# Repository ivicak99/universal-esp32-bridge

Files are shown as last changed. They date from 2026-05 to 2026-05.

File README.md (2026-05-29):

# Universal ESP32 Button/Signal Bridge

Compact **ESP32-S3** board for personal automation — safely interfaces with low-voltage
buttons, LEDs, buzzers, and control panels (intercoms, appliance panels, remotes,
ventilation controls).

> ⚠️ **LOW VOLTAGE ONLY — NOT designed to switch 230 V mains.** Relays use low-voltage
> contacts only.

**Status:** paper design, rev 0.1 (schematic notes + KiCad project skeleton; not yet
laid out or prototyped).

## Features

- **ESP32-S3-WROOM-1-N8** module (pre-certified, no PSRAM so GPIO35/36/37 stay free)
- USB-C power + **native USB-Serial-JTAG** programming (no CH340/CP2102 needed)
- 5 V external input + AMS1117-3.3 regulator
- **8** optically isolated inputs (≈3–24 V DC, constant-current front end, active-low)
- **8** PhotoMOS isolated dry-contact outputs (AQY212GS, ≤60 V / ≤0.5 A)
- **2** optional mechanical relay outputs (MOSFET-driven, flyback, LV contacts only)
- **4** capacitive-touch injection outputs (100 k / 470 k / 1 M selectable)
- Status LED, BOOT + RESET buttons, UART debug + spare-GPIO headers
- Screw terminals + test points; 4-layer; 0603-min passives; JLCPCB/LCSC sourcing

## Files

| File | Description |
|---|---|
| [DESIGN.md](DESIGN.md) | Block diagram, GPIO map, strapping-pin policy, per-block schematics, ERC/DRC notes, warnings, I/O-expander fallback |
| [BOM.csv](BOM.csv) | Bill of materials with example parts / LCSC codes (verify before ordering) |
| [block-diagram.txt](block-diagram.txt) | ASCII block diagram |
| `universal-esp32-bridge.kicad_pro` | KiCad 8 project |
| `universal-esp32-bridge.kicad_sch` | Starter schematic (design notes embedded) |

## GPIO summary

23 signals on direct ESP32-S3 GPIO (inputs 4/5/6/7/15/16/17/18, PhotoMOS
8/9/10/11/12/13/14/21, relays 35/36, cap-inject 37/38/39/40, LED 2). Strapping pins
GPIO3/45/46 left unconnected; GPIO0 used only by BOOT button. See [DESIGN.md](DESIGN.md).

## Disclaimer

Unverified paper design. Build and bring up one channel of each type before populating
all channels. Confirm all part numbers and footprints before ordering.

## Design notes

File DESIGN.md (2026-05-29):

# Universal ESP32 Button/Signal Bridge — Design Package

**Rev:** 0.3 (ERC-clean, real footprints, tidied for review)
**Date:** 2026-05-29
**MCU module:** ESP32-S3-WROOM-1-N8 (8 MB flash, **no** PSRAM — chosen so GPIO35/36/37 stay free)
**Regulator:** SY8089AAAC buck (2.7–5.5 V in, 2 A) → 3.3 V  *(replaced AMS1117 for Wi-Fi-peak headroom)*
**PCB:** 4-layer, signal / GND / PWR / signal
**Passives:** 0603 minimum (0805/1206 where power dictates). No 0201/01005.
**Sourcing target:** JLCPCB / LCSC

> ⚠️ **SAFETY / SCOPE**
> This board is for **low-voltage signal-level** automation only (≈3–24 V DC on inputs,
> ≤60 V / ≤0.5 A on isolated outputs). It is **NOT designed to switch 230 V mains** and
> must never be wired to mains. The mechanical relays use low-voltage contacts only.
> Silk legend to print: **"LOW VOLTAGE ONLY — NOT FOR MAINS (230 V) SWITCHING".**

---

## 0. Realized KiCad schematic (rev 0.3) — STATUS

The paper design is now a **real, ERC-clean KiCad 10 hierarchical schematic** with actual
library symbols, **datasheet-accurate footprints**, and a **tidied, human-readable layout**
(each pin routed to an offset net label; channels laid out as clean columns). **No PCB
layout yet** (per instruction — layout waits until you're happy with the schematic).

**Rev 0.3 changes:**
- **HK4100F-DC5V-SHG footprint built** (6-pad THT land pattern from the LCSC/EasyEDA part,
  matches datasheet 15.5×10.5 mm). Pin map: coil = 3/4, COM = 5/6 (tied), NO = 1, NC = 2.
  Custom symbol added so symbol pins match footprint pads. *(NO/NC could be swapped —
  low-risk, confirm against datasheet at build.)*
- **AQY212GS footprint corrected** to SOP-4 **2.54 mm pitch** (LS 6.8 mm) — the earlier
  1.27 mm assumption was wrong. Pinout confirmed 1=A, 2=K, 3/4=load.
- **EL357N LCSC code corrected to C6649** (the previous C124981 was a trimmer pot, not the
  opto!). Package confirmed SOP-4 2.54 mm; footprint generated.
- Footprints `bridge:HK4100F-DC5V-SHG`, `bridge:AQY212GS_SOP-4`, `bridge:EL357N_SOP-4`
  live in `footprints/bridge.pretty/` (generated via easyeda2kicad from the LCSC parts).
- Schematic re-laid-out for readability (bigger pages for the 8-channel sheets; labels
  offset from pins on short stubs routed by each pin's true orientation).

**ERC result:** `0 errors, 0 warnings` (KiCad 10.0.3 `kicad-cli sch erc`). Netlist verified:
160 components, 121 nets; rails, FB divider, reset/boot, relay coils all correctly wired;
**galvanic isolation barrier confirmed intact** (no field-side input/output net touches GND
or the ESP32).

**Project files (repo root):**
| File | Contents |
|---|---|
| `universal-esp32-bridge.kicad_sch` | Root sheet (instantiates the 6 child sheets) |
| `power.kicad_sch` | USB-C, diode-OR, SY8089 buck, rails, test points |
| `mcu.kicad_sch` | ESP32-S3-WROOM-1, reset/boot, status LED, UART + spare headers |
| `inputs.kicad_sch` | 8× isolated input channels |
| `photomos.kicad_sch` | 8× PhotoMOS dry-contact outputs |
| `relays.kicad_sch` | 2× relay channels |
| `capinject.kicad_sch` | 4× cap-injection channels |
| `bridge.kicad_sym` | Custom symbols: SY8089, AQY212GS |
| `sym-lib-table` / `fp-lib-table` | Point to KiCad 10 global libs + the custom lib |
| `schematic.pdf` | Rendered schematic (view without KiCad) |
| `gen/` | Python generator (`build.py`, `kisch.py`) that emits the project |

**Two engineering changes made while realizing the design:**
1. **Regulator → SY8089 buck.** AMS1117's dropout was marginal on the ~4.6 V diode-OR rail
   at Wi-Fi peaks. SY8089 (2.7–5.5 V in) handles the low rail with margin and is more
   efficient. FB divider R3=453 k / R4=100 k → 3.32 V.
2. **Input front-end → fixed 2.2 kΩ (1206), not a CRD.** Constant-current diodes are poorly
   stocked on LCSC. A 2.2 kΩ/1206 series resistor + the high-CTR EL357N covers 3–24 V
   (≈0.9 mA→10 mA) and the 1206 handles the ~0.24 W at 24 V. Anti-parallel 1N4148WS gives
   reverse protection. (A CRD is still a valid swap if you prefer constant current.)

**To regenerate / re-run ERC:**
```
cd gen && python3 build.py
/Applications/KiCad/KiCad.app/Contents/MacOS/kicad-cli sch erc \
    ../universal-esp32-bridge.kicad_sch --exit-code-violations
```

---

## 1. Block Diagram

```
                              USB-C (power + native USB-Serial-JTAG)
                                 │ VBUS 5V        │ D+ / D-
                                 │                │ (GPIO20 / GPIO19)
                  ┌──────────────┴───┐        ┌───┴───────────────┐
   EXT 5V IN ───►│  Diode-OR (SS54)  │        │ USBLC6-2SC6 ESD    │
   (screw term)  │  reverse-prot     │        └───┬───────────────┘
                 └──────────┬────────┘            │
                            │ 5V rail (~4.6V)      │
              ┌─────────────┼──────────────┐      │
              │             │              │      │
        ┌─────┴─────┐  ┌────┴─────┐   ┌────┴──────┴──────────────────┐
        │ AMS1117-  │  │ Relay    │   │      ESP32-S3-WROOM-1-N8       │
        │ 3.3 LDO   │  │ coils 5V │   │  (3.3V, native USB, buttons)  │
        └─────┬─────┘  └────┬─────┘   └──┬───┬────┬────┬────┬────┬─────┘
              │ 3.3V rail   │            │   │    │    │    │    │
              ├─────────────┼────────────┘   │    │    │    │    │
              │             │                 │    │    │    │    │
   ┌──────────┴───┐  ┌──────┴──────┐  ┌──────┴─┐ ┌┴────┴┐ ┌─┴────┴─┐
   │ 8× ISOLATED  │  │ 8× PhotoMOS │  │ 2× RLY │ │4× CAP│ │ STATUS │
   │ INPUTS       │  │ DRY-CONTACT │  │ driver │ │ inject│ │ LED    │
   │ (opto + CRD) │  │ OUTPUTS     │  │ +flybk │ │ 100k/ │ │ GPIO2  │
   │ 3–24V DC     │  │ ≤60V/≤0.5A  │  │ MOSFET │ │ 470k/ │ └────────┘
   └──────┬───────┘  └──────┬──────┘  └───┬────┘ │ 1M    │
          │                 │             │      └──┬────┘
     screw terminals   screw terminals  screw t.  pads/term
     IN1..IN8 (+/-)    OUT1..OUT8 (A/B) RLY1/2    CAP1..4

   Test points: 3V3, 5V, GND, IN1..8 (logic side), OUT1..8, plus BOOT/EN.
```

Full-resolution block diagram source: see `block-diagram.txt`.

---

## 2. GPIO Pin Map (ESP32-S3-WROOM-1)

**Reserved / avoided:** GPIO0 (BOOT strap), GPIO3 / GPIO45 / GPIO46 (straps),
GPIO19/GPIO20 (native USB D-/D+), GPIO43/GPIO44 (UART0 console — kept free for debug).

| Function | Signal | GPIO | Notes |
|---|---|---|---|
| Isolated input 1  | IN1 | GPIO4  | opto pulls LOW when external signal present |
| Isolated input 2  | IN2 | GPIO5  | (active-low, invert in firmware) |
| Isolated input 3  | IN3 | GPIO6  | |
| Isolated input 4  | IN4 | GPIO7  | |
| Isolated input 5  | IN5 | GPIO15 | |
| Isolated input 6  | IN6 | GPIO16 | |
| Isolated input 7  | IN7 | GPIO17 | |
| Isolated input 8  | IN8 | GPIO18 | |
| PhotoMOS out 1 | OUT1 | GPIO8  | HIGH = contact closed |
| PhotoMOS out 2 | OUT2 | GPIO9  | |
| PhotoMOS out 3 | OUT3 | GPIO10 | |
| PhotoMOS out 4 | OUT4 | GPIO11 | |
| PhotoMOS out 5 | OUT5 | GPIO12 | |
| PhotoMOS out 6 | OUT6 | GPIO13 | |
| PhotoMOS out 7 | OUT7 | GPIO14 | |
| PhotoMOS out 8 | OUT8 | GPIO21 | |
| Relay 1 drive | RLY1 | GPIO35 | via MOSFET; HIGH = energized |
| Relay 2 drive | RLY2 | GPIO36 | |
| Cap inject 1 | CAP1 | GPIO37 | through 100k/470k/1M jumper |
| Cap inject 2 | CAP2 | GPIO38 | |
| Cap inject 3 | CAP3 | GPIO39 | |
| Cap inject 4 | CAP4 | GPIO40 | |
| Status LED | LED | GPIO2  | active-high through 1k |
| Boot button | — | GPIO0  | strap, 10k PU + 0.1µF, button to GND |
| Reset button | — | EN | 10k PU + 1µF, button to GND |
| USB D- | — | GPIO19 | native USB-Serial-JTAG |
| USB D+ | — | GPIO20 | |
| (free / spare) | — | GPIO1, GPIO41, GPIO42, GPIO47, GPIO48 | bring to a header for future use |

**23 signals assigned, 5 GPIOs spare.** GPIO35/36/37 are only free on **non-PSRAM**
modules (N8). If you buy an `R8` (octal PSRAM) variant, those three pins disappear —
re-map relays/cap1 to spares (GPIO47/48/41).

### 2.1 Strapping-pin handling (explicit)

ESP32-S3 has 4 strapping pins sampled at reset. This design's policy:

| Strap pin | Default latch | Used in this design? | Handling |
|---|---|---|---|
| GPIO0 | 1 = SPI boot  | **Yes — BOOT button** | 10k pull-up + 0.1µF + button to GND. Default HIGH = normal boot; pull LOW only while pressing BOOT. No other load on this net. |
| GPIO3 | float = JTAG src | **No** | Left unconnected (no-connect flag). Not routed to any channel. |
| GPIO45 | 0 = VDD_SPI 3.3V | **No** | Left unconnected. Do not load — must read its default at boot. |
| GPIO46 | 0 (ROM msg ctrl), input-only | **No** | Left unconnected. Input-only anyway, so never used as an output. |

No isolated-input, PhotoMOS, relay, or cap-inject channel is mapped onto a strapping
pin. The only strap intentionally driven is GPIO0, and only by the BOOT button — exactly
its intended ESP-IDF use. This keeps power-on boot deterministic.

> Also note GPIO19/20 (USB) and GPIO43/44 (UART0) are reserved, not channel pins.

### 2.2 I/O Expander Option (fallback — NOT used in V1)

**V1 default = direct ESP32-S3 GPIO** for every channel (28 usable pins ≥ 23 needed, so
no expander is required and none is fitted). This section documents the fallback **only**
for the case where layout/routing of 22 channel traces to the module proves too messy on
the chosen board size — per your instruction, propose the expander before ever cutting
channels.

**Proposed expander: MCP23017** (16-bit I²C GPIO expander, 0603-friendly SSOP/SOIC,
on LCSC, 5V/3.3V tolerant, two address pins → up to 8 on one bus, has INT outputs).

What moves to the expander vs. stays direct:

| Channel group | On expander? | Why |
|---|---|-----|
| 8 PhotoMOS outputs | ✅ yes | Slow on/off; I²C latency irrelevant. |
| 2 relay outputs | ✅ yes | Same — set-and-forget. |
| Status LED | ✅ yes | Trivial. |
| 8 isolated inputs | ⚠️ optional | OK via MCP23017 INT pin → 1 ESP32 GPIO interrupt; on-chip pull-ups + INT-on-change. Slightly more firmware. |
| **4 cap-inject** | ❌ **stay direct** | Charge-transfer timing needs real-time GPIO toggling — an I²C expander is far too slow. Always on native ESP32 GPIO. |

**Two sizing options:**
- **1× MCP23017** → all 8 PhotoMOS + 2 relays + status LED (11 of 16 pins). Inputs + 4
  cap-inject stay on direct GPIO. Frees ~11 ESP32 pins. Cost: 1 chip, I²C (SDA/SCL =
  e.g. GPIO8/GPIO9) + 1 INT line if you later move inputs over.
- **2× MCP23017** (addresses 0x20/0x21) → bank A = 8 outputs+2 relays+LED, bank B = 8
  inputs (with INT). Only cap-inject + I²C + INTs remain direct: **~6 ESP32 GPIOs total.**
  This is also what would let a pin-limited C3 run the full board — but we are staying on
  S3, so this is purely a routing-relief option.

**Trade-offs to weigh before choosing it:**
- Adds I²C bus (2 pull-ups 4.7k), 1–2 chips, decoupling — more BOM, but *fewer* long
  channel traces fanning out to the module (often a net routing win on a dense 4-layer).
- Output update rate via I²C is ~fine (sub-ms for a few pins); inputs lose hardware
  per-pin interrupt granularity (one shared INT, read register to find which pin).
- Firmware: ESPHome has an `mcp23017`/`mcp23xxx` platform, so channels still expose
  cleanly later.

**Decision for V1: do NOT populate an expander.** Keep the MCP23017 footprint(s) + I²C
pull-ups as an **optional DNP footprint** on the board if you want a no-respin escape
hatch; otherwise route direct. Revisit only if 4-layer routing of the 22 channels can't
close at the target board size.

---

## 3. Schematic Design (per-block, as readable netlists)

Reference designators below match the KiCad skeleton sheets you'll wire up.

### 3.1 Power

```
USB-C J1:
  VBUS ──► D1 (SS54 Schottky, anode VBUS, cathode 5V_RAIL)
  CC1 ── R1 5.1k ── GND        (Rd, sink advertise)
  CC2 ── R2 5.1k ── GND
  D+/D- ── USBLC6-2SC6 (U2) ── GPIO20 / GPIO19   (ESD clamp + pass-through)
  SHIELD ── (NP) ── chassis/GND via 1M ∥ 4.7nF footprint

EXT 5V screw terminal J2 (5V, GND):
  5V_in ──► D2 (SS54, anode in, cathode 5V_RAIL)   (reverse-protect + OR with USB)

5V_RAIL:
  C1 100µF (1206/electrolytic) + C2 0.1µF  to GND   (bulk)
  ──► AMS1117-3.3 (U3) IN
       U3 OUT = 3V3_RAIL
       C3 22µF + C4 0.1µF on OUT to GND

3V3_RAIL:
  C5 22µF + C6 10µF + C7 0.1µF near module 3V3 pin
  TVS optional footprint D3 (SMAJ5.0A) across 5V_RAIL→GND
```

> Note: diode-OR drops the rail to ≈4.6 V. AMS1117 dropout at ~500 mA is ~1 V, leaving
> ~3.5 V headroom for the 3.3 V output — adequate but not generous. See Warnings §7.

### 3.2 ESP32-S3 module (U4 = ESP32-S3-WROOM-1-N8)

```
3V3 ── module 3V3, decoupled as above
EN  ── R3 10k to 3V3 ; C8 1µF to GND ; SW1 (RESET) to GND
GPIO0 ── R4 10k to 3V3 ; C9 0.1µF to GND ; SW2 (BOOT) to GND
GPIO19 ── USB D- (via U2)
GPIO20 ── USB D+ (via U2)
GPIO43/44 (U0TXD/RXD) ── 3-pin debug header J3 (TX, RX, GND)
Spare GPIOs (1,41,42,47,48) ── 5-pin expansion header J4
GND ── module GND pads + thermal pad
```

### 3.3 Isolated Input channel (×8, IN1…IN8) — repeat block

```
Screw terminal Jx (IN+, IN-):
  IN+ ──► CRD1 (constant-current diode ~2 mA, e.g. 1N5305 / CRD-2mA)
        ──► opto LED anode (U_INx, EL357N)
  opto LED cathode ──► IN-
  D_revx (1N4148WS) anti-parallel across opto LED (reverse clamp)
  TVS optional footprint (SMAJ24A) across IN+/IN-   [DNP default]

Opto output side (EL357N transistor):
  collector ──► R_pux 10k to 3V3   AND  ──► node INx_LOGIC
  emitter   ──► GND
  Optional RC filter footprint:
      INx_LOGIC ── R_fx (1k, DNP/0Ω default) ── INx_FILT ── C_fx (100nF, DNP) ── GND
  INx_FILT (or INx_LOGIC if RC unpopulated) ──► ESP32 GPIO
  Test point TP_INx on the logic node.
```

- **Idle (no external signal):** opto off → GPIO pulled HIGH by 10k.
- **Signal present:** opto on → GPIO pulled LOW. Treat as **active-low** in firmware.
- CRD gives ~constant LED current from ~3 V to 24 V, so brightness/threshold is
  consistent across the whole range and the series resistor never overheats.
- CRD inherently blocks reverse polarity (it's a diode) → polarity protection built in.

### 3.4 PhotoMOS dry-contact output (×8, OUT1…OUT8) — repeat block

```
ESP32 GPIO ──► R_dx 330Ω ──► PhotoMOS LED anode (U_OUTx, AQY212GS)
                              PhotoMOS LED cathode ──► GND
PhotoMOS load pins (pins 4 & 6) ──► screw terminal Jx (OUTx_A, OUTx_B)
  Optional series footprint F_x (0Ω / fuse / PTC) in OUTx_A leg  [0Ω default]
  Optional TVS/snubber footprint across OUTx_A/B  [DNP]
Test point TP_OUTx on OUTx_A.
```

- ~6.4 mA LED drive from 3.3 V through 330 Ω (AQY212 trigger IF ≈ 3 mA → solid margin).
- Output is a **bidirectional isolated solid-state contact** (no polarity), behaves like
  a momentary/maintained button. AQY212GS: 60 V / 550 mA / ~0.5 Ω on-resistance.
- GPIO HIGH = contact closed.

### 3.5 Mechanical relay output (×2, RLY1/RLY2) — optional, repeat block

```
ESP32 GPIO ──► R_gx 100Ω ──► gate of Q_x (AO3400A, logic-level N-MOSFET)
  R_pdx 100k gate-to-GND (hold off during boot)
  Q_x source ──► GND
  Q_x drain  ──► relay coil (-)   [K_x = HK4100F-DC5V or G5NB-1A-E-5VDC]
  relay coil (+) ──► 5V_RAIL
  D_fbx flyback (1N4007/M7 or SS14) across coil, cathode to 5V
Relay contacts (COM / NO [/ NC]) ──► screw terminal Jx
  Optional RC snubber footprint across contacts  [DNP]
Silk: "LV CONTACTS ONLY"
```

- Driven by MOSFET, never directly from the GPIO. Gate pulldown keeps relay off while
  GPIO0/straps settle at boot. Flyback diode mandatory.

### 3.6 Capacitive injection output (×4, CAP1…CAP4) — repeat block

```
ESP32 GPIO ──► three parallel 0603 resistor footprints to common node CAPx_OUT:
      R_100k  (100 kΩ)   } populate ONE, or use solder-jumper SJ_x to select
      R_470k  (470 kΩ)   }
      R_1M    (1 MΩ)     }
CAPx_OUT ──► 2-pin terminal / pad to external touch pad
  Optional series C footprint (DNP) + ESD diode footprint (DNP)
Test point TP_CAPx.
```

- Default-populate 470 kΩ; leave the other two unpopulated. Or fit all three and select
  with the solder jumper. High series R limits current and lets the GPIO inject a
  charge-transfer signal into an external capacitive pad for experimentation.

### 3.7 Status LED

```
GPIO2 ──► R_led 1k ──► LED1 (0603, green) ──► GND   (active-high)
```

---

## 4. Connectors & Test Points

| Ref | Type | Purpose |
|---|---|---|
| J1 | USB-C 16-pin SMD (TYPE-C-31-M-12) | Power + native USB programming |
| J2 | 2-pos 3.5 mm screw terminal | External 5 V in |
| IN1–IN8  | 2-pos 3.5 mm screw terminal (×8) | Isolated inputs (IN+/IN-) |
| OUT1–OUT8| 2-pos 3.5 mm screw terminal (×8) | PhotoMOS dry contacts (A/B) |
| RLY1–RLY2| 3-pos 3.5 mm screw terminal (×2) | Relay COM/NO/NC |
| CAP1–CAP4| 2-pos 3.5 mm screw terminal (×4) | Cap-inject outputs |
| J3 | 3-pin 2.54 header | UART0 debug (TX/RX/GND) |
| J4 | 5-pin 2.54 header | Spare GPIO expansion |
| TP_* | 1.0 mm test pads | 3V3, 5V, GND, IN1-8, OUT1-8 |

> JST-XH alternative: every 3.5 mm terminal footprint can be swapped for JST-XH if you
> prefer cable connectors — keep the same pin order. Pick one in layout; don't fit both.

---

## 5. Suggested BOM (real parts)

See `BOM.csv` for the machine-readable version. Highlights:

| Block | Part | Mfr / Example | LCSC* | Notes |
|---|---|---|---|---|
| MCU module | ESP32-S3-WROOM-1-N8 | Espressif | verify| pre-certified, no PSRAM |
| LDO 3.3V | AMS1117-3.3 | various | C6186 | 1 A, beginner-proof |
| USB-C conn | TYPE-C-31-M-12 (16P) | various | C165948 | power+USB |
| USB ESD | USBLC6-2SC6 | ST | C7519 | D+/D- clamp |
| OR/rev diode | SS54 (SMC) | various | C22452| low-Vf 5 A Schottky |
| Input opto | EL357N(B) (×8) | Everlight | C124981 | SMD, high CTR |
| Input CCR | constant-current diode ~2 mA (×8) | e.g. 1N5305 / CRD | verify| see Warnings §7 |
| Input clamp  | 1N4148WS (×8) | various | C2128 | reverse clamp |
| PhotoMOS | AQY212GS (×8) | Panasonic | verify| 60V/550mA/0.5Ω |
| PhotoMOS alt | CPC1017N (×8) | IXYS/Clare | verify| 60V/100mA cheap alt |
| Relay | HK4100F-DC5V (×2) | HuiKe | C39562| LV contacts only |
| Relay MOSFET | AO3400A (×2) | AOS | C20917| logic-level N-ch |
| Flyback | 1N4007 / M7 (×2) | various | C95872| across coil |
| Status LED | 0603 green | various | — | |
| Buttons | 6×3.5 mm SMD tact (×2) | various | C318884| BOOT + RESET |
| Bulk caps | 100µF/16V, 22µF, 10µF | various | — | power filtering |
| Passives | 0603 R/C as listed | various | — | 1% resistors |
| Terminals | 3.5 mm screw, 2P/3P | various | — | I/O |

\* **LCSC codes must be verified before ordering** — codes drift and packaging
varies. Treat the manufacturer part numbers as authoritative and confirm the LCSC
stock code + footprint on lcsc.com at order time.

---

## 6. ERC / DRC Notes

**ERC (schematic):**
- Every opto/PhotoMOS LED needs its series element (CRD or 330 Ω) — ERC won't catch a
  missing current limit; check manually.
- Mark `5V_RAIL`, `3V3_RAIL`, `GND` as global power nets; add a `PWR_FLAG` on the LDO
  output, the 5V rail, and GND or ERC will report "input power pin not driven".
- Set unused module pins to "unconnected" (place no-connect flags) to silence ERC.
- Active-low inputs are intentional — don't let ERC/firmware assume active-high.
- BOOT (GPIO0) and EN have pull-ups + caps; verify no other driver fights them.

**DRC (layout, 4-layer):**
- **Isolation:** keep a clearance gap (≥1.5–2 mm, ideally a routed slot) between the
  field side (screw terminals / opto+PhotoMOS LED-output pins, relay contacts) and the
  logic side. The whole point of the optos/PhotoMOS is galvanic isolation — don't pour
  the logic GND plane under the field-side terminals. Use separate "field" copper.
- Inputs at 24 V are low energy, but still give input traces ≥0.3 mm and terminal-to-
  terminal spacing per your terminal pitch.
- Relay coil + PhotoMOS traces that may carry up to 0.5 A: ≥0.4 mm (16 mil) traces.
- USB D+/D-: route as a loose differential pair, short, away from switching nodes;
  put the USBLC6 right at the connector.
- Decoupling caps within a few mm of the module 3V3 pin; bulk cap near the LDO.
- Thermal: AMS1117 needs copper pour on its tab for >300 mA continuous.
- Place the module antenna at a board edge with **keep-out** (no copper/plane under the
  antenna) per Espressif's WROOM-1 layout guide.
- Add fab fiducials + the "NOT FOR MAINS" silk legend.

---

## 7. Warnings & Uncertain Items

1. **Wide-range input current limiting (most important).** A single fixed resistor that
   gives enough opto current at 3 V *and* doesn't cook itself / over-drive the opto at
   24 V is not really possible (8:1 range). The design uses a **constant-current diode
   (CRD ~2 mA)** which solves this elegantly and adds reverse protection — but:
   - CRD knee voltage + opto Vf (~1.2 V) means the very bottom of the 3 V spec is
     marginal. Validate with your exact CRD; if 3 V must be rock-solid, pick a low-knee
     CRD or a lower-Vf opto.
   - **Alternative if you can't source a CRD on LCSC:** fit a series resistor instead
     (footprint provided), e.g. 2.2 kΩ in **1206** (handles the ~0.24 W at 24 V), and
     accept that current varies 1–10 mA across the range. The EL357N's high CTR copes.
     I left both footprints so you can choose at build time.

2. **LCSC part numbers — now verified for the key actives** against JLCPCB (May 2026):
   ESP32-S3-WROOM-1-N8 **C2913198**, SY8089AAAC **C78988**, AQY212GS **C719745**,
   HK4100F-DC5V-SHG **C12072**, USB-C TYPE-C-31-M-12 **C165948**, AO3400A **C20917**.
   EL357N corrected to **C6649** (the old C124981 was a trimmer pot — fixed). Still confirm
   before ordering: USBLC6-2SC6 (C7519), SS54 (C22452), 1N4148WS (C2128), M7 (C95872). Passives are generic.

3. **Power rail headroom — resolved by the buck.** Diode-OR'd 5 V rail sits at ~4.6 V.
   The **SY8089 buck (2.7–5.5 V in)** handles this with large margin, unlike the original
   AMS1117 LDO (marginal dropout at Wi-Fi peaks). If you ever revert to an LDO, use a
   low-Vf P-FET ideal-diode for the OR-ing instead of the Schottky.

10. **Relay footprint — built (rev 0.3).** Real 6-pad HK4100F land pattern now in
    `bridge.pretty`. Remaining low-risk item: **NO/NC pad assignment** (pins 1 vs 2) is from
    decoding the EasyEDA symbol; the relay still works if swapped (just relabel the terminal),
    but confirm against the HUIKE datasheet before final.

11. **Custom symbols (SY8089, AQY212GS, HK4100F) pinouts.** SY8089 from Silergy datasheet
    (1=EN,2=GND,3=LX,4=IN,5=FB). AQY212GS 1=A,2=K,3/4=load (bidirectional). HK4100F coil=3/4,
    COM=5/6, NO=1, NC=2. All symbol pins match their generated footprints' pad numbers.

4. **USB current.** With plain 5.1 k CC pulldowns you only guarantee USB default current
   (~500 mA). ESP32 WiFi + both relays + several PhotoMOS can exceed that. **Power the
   relays/heavy loads from the EXT 5 V terminal** if using both relays hard, or add a
   USB-PD/BC1.2 negotiator. Documented, not auto-handled.

5. **Native USB vs UART.** I used the S3's built-in USB-Serial-JTAG (GPIO19/20) → no
   CH340/CP2102 needed. Auto-download usually works without touching buttons, but BOOT +
   RESET are included for the cases where it doesn't. If you'd rather have a classic
   USB-UART bridge with auto-reset (DTR/RTS), that's a different sub-circuit.

6. **Module variant matters.** Buy **N8 (no PSRAM)**. An `R8`/octal-PSRAM module steals
   GPIO35/36/37 — the relay + CAP1 pins. Re-map to spares if you must use R8.

7. **Isolation is only as good as the layout.** The optos/PhotoMOS provide galvanic
   isolation, but a sloppy 4-layer pour that runs the logic ground plane under the
   field-side terminals destroys it. Respect the isolation gap in §6.

8. **Test-point count is large.** 3V3+5V+GND + 8 inputs + 8 outputs = 19 pads minimum.
   They eat board area; consider a debug header block instead of individual loops if
   space is tight.

9. **This is a paper design, not validated silicon.** No SPICE sim or prototype yet.
   Build one channel of each type first (1 input, 1 PhotoMOS, 1 relay, 1 cap) on the
   first article and bring up firmware before populating all 22 channels.

---

## 8. Firmware GPIO hints (for later — ESPHome/MQTT/Matter)

- Inputs: `binary_sensor` with `inverted: true` (active-low), add `delayed_on/off` or
  the on-board RC for buzzer/blinking sources.
- PhotoMOS outputs: `switch` / `output` (active-high). For "button press" use a momentary
  `on_press` → turn on, delay 100–300 ms, turn off.
- Relays: `switch`, active-high; consider `restore_mode: ALWAYS_OFF`.
- Cap inject: `output` (or `esp32_touch` experiments) — start LOW.
- Status LED: `light`/`status_led` on GPIO2.
- Do **not** assign anything to GPIO0/3/45/46 in firmware.

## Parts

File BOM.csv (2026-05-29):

Item | Qty | References | Value | Footprint | Manufacturer Part | LCSC | JLCPCB | Notes
1 | 1 | U3 | ESP32-S3-WROOM-1-N8 | RF_Module:ESP32-S3-WROOM-1 | ESP32-S3-WROOM-1-N8 | C2913198 | Yes | Buy N8 (no PSRAM) so GPIO35/36/37 stay free
2 | 1 | U2 | SY8089AAAC | Package_TO_SOT_SMD:SOT-23-5 | SY8089AAAC | C78988 | Yes | Buck 2.7-5.5Vin/2A; Vout=0.6*(1+R3/R4)
3 | 1 | U1 | USBLC6-2SC6 | Package_TO_SOT_SMD:SOT-23-6 | USBLC6-2SC6 | C7519 | Yes | USB D+/D- ESD (verify code)
4 | 1 | J1 | USB-C | Connector_USB:USB_C_Receptacle_HRO_TYPE-C-31-M-12 | TYPE-C-31-M-12 | C165948 | Yes | 16-pin USB2.0 Type-C
5 | 8 | U4-U11 | EL357N | bridge:EL357N_SOP-4 | EL357N(B)(TA)-G | C6649 | Yes | Input optocoupler SOP-4 2.54mm (LCSC code corrected from C124981)
6 | 8 | U12-U19 | AQY212GS | bridge:AQY212GS_SOP-4 | AQY212GS | C719745 | Yes | PhotoMOS 60V/1A; SOP-4 2.54mm pitch (LS6.8)
7 | 2 | K1;K2 | HK4100F-DC5V | bridge:HK4100F-DC5V-SHG | HK4100F-DC5V-SHG | C12072 | Yes | 6-pad land pattern from datasheet; coil=3/4 COM=5/6 NO=1 NC=2
8 | 2 | Q1;Q2 | AO3400A | Package_TO_SOT_SMD:SOT-23 | AO3400A | C20917 | Yes | Logic-level N-MOSFET relay driver
9 | 2 | D1;D2 | SS54 | Diode_SMD:D_SMC | SS54 | C22452 | Yes | Diode-OR / reverse protect (verify code)
10 | 8 | D4-D11 | 1N4148WS | Diode_SMD:D_SOD-323 | 1N4148WS | C2128 | Yes | Input anti-parallel reverse clamp
11 | 2 | D12;D13 | M7 | Diode_SMD:D_SMA | M7 (1N4007 SMD) | C95872 | Yes | Relay coil flyback
12 | 1 | D3 | LED green | LED_SMD:LED_0603_1608Metric | (any 0603 green) | - | Yes | Status LED on IO2
13 | 1 | L1 | 2.2uH | Inductor_SMD:L_1210_3225Metric | (2.2uH >=1A) | - | Yes | Buck inductor; pick >=1A Isat
14 | 8 | R8;R11;R14;R17;R20;R23;R26;R29 | 2.2k | Resistor_SMD:R_1206_3216Metric | (2.2k 1206) | - | Yes | Input current-limit (1206 for power at 24V)
15 | 8 | R32-R39 | 330 | Resistor_SMD:R_0603_1608Metric | (330 0603) | - | Yes | PhotoMOS LED drive
16 | 10 | R5;R6;R9;R12;R15;R18;R21;R24;R27;R30 | 10k | Resistor_SMD:R_0603_1608Metric | (10k 0603) | - | Yes | Input pull-ups + EN/BOOT pull-ups
17 | 9 | R7;R10;R13;R16;R19;R22;R25;R28;R31 | 1k | Resistor_SMD:R_0603_1608Metric | (1k 0603) | - | Yes | Input RC filter series + status LED
18 | 7 | R4;R41;R43;R44;R47;R50;R53 | 100k | Resistor_SMD:R_0603_1608Metric | (100k 0603) | - | Yes | FB-bottom + MOSFET gate pulldown + cap-inject(100k)
19 | 4 | R45;R48;R51;R54 | 470k | Resistor_SMD:R_0603_1608Metric | (470k 0603) | - | Yes | Cap-inject (default populate)
20 | 4 | R46;R49;R52;R55 | 1M | Resistor_SMD:R_0603_1608Metric | (1M 0603) | - | Yes | Cap-inject option
21 | 1 | R3 | 453k | Resistor_SMD:R_0603_1608Metric | (453k 0603 1%) | - | Yes | Buck FB top -> 3.32V
22 | 2 | R40;R42 | 100 | Resistor_SMD:R_0603_1608Metric | (100 0603) | - | Yes | MOSFET gate series
23 | 2 | R1;R2 | 5.1k | Resistor_SMD:R_0603_1608Metric | (5.1k 0603) | - | Yes | USB-C CC Rd pulldowns
24 | 12 | C2;C6;C7;C8;C10-C17 | 100nF | Capacitor_SMD:C_0603_1608Metric | (100nF X7R 0603) | - | Yes | Decoupling + input RC + BOOT
25 | 2 | C3;C4 | 22uF | Capacitor_SMD:C_0805_2012Metric | (22uF 10V X7R 0805) | - | Yes | Buck in/out
26 | 1 | C1 | 100uF | Capacitor_SMD:C_1206_3216Metric | (100uF 16V) | - | Yes | 5V bulk
27 | 1 | C5 | 1uF | Capacitor_SMD:C_0603_1608Metric | (1uF 0603) | - | Yes | EN RC
28 | 1 | C9 | 10uF | Capacitor_SMD:C_0603_1608Metric | (10uF 0603) | - | Yes | 3V3 bulk near module
29 | 2 | SW1;SW2 | tactile | Button_Switch_SMD:Panasonic_EVQPUJ_EVQPUA | (SMD tact) | - | Yes | RESET + BOOT (verify exact button/footprint)
30 | 21 | J2;J5-J20;J23-J26 | Screw term 2P | TerminalBlock:TerminalBlock_MaiXu_MX126-5.0-02P_1x02_P5.00mm | (5.0mm 2P) | - | Yes | EXT5V + 8 inputs + 8 PhotoMOS + 4 cap-inject
31 | 2 | J21;J22 | Screw term 3P | TerminalBlock:TerminalBlock_MaiXu_MX126-5.0-03P_1x03_P5.00mm | (5.0mm 3P) | - | Yes | Relay COM/NO/NC
32 | 1 | J3 | Header 1x3 | Connector_PinHeader_2.54mm:PinHeader_1x03_P2.54mm_Vertical | (2.54 1x3) | - | Yes | UART debug
33 | 1 | J4 | Header 1x6 | Connector_PinHeader_2.54mm:PinHeader_1x06_P2.54mm_Vertical | (2.54 1x6) | - | Yes | Spare GPIO + GND
34 | 23 | TP1-TP23 | TestPoint | TestPoint:TestPoint_Pad_D1.5mm | (pad) | - | n/a | 3V3/5V/GND/IN1-8/OUT1-8/CAP1-4
NOTE |  |  |  |  |  |  |  | Cap-inject: schematic carries all 3 R per channel (100k/470k/1M); POPULATE ONE (default 470k). So actual populated cap-inject R = 4, not 12.
NOTE |  |  |  |  |  |  |  | LCSC codes verified against JLCPCB May 2026: ESP32 C2913198, buck C78988, EL357N C6649, AQY212GS C719745, relay C12072, USB-C C165948, AO3400A C20917.
NOTE |  |  |  |  |  |  |  | bridge:* footprints (relay/PhotoMOS/opto) generated from EasyEDA/LCSC (datasheet-accurate) and live in footprints/bridge.pretty. HK4100F NO/NC could be swapped - confirm before final.

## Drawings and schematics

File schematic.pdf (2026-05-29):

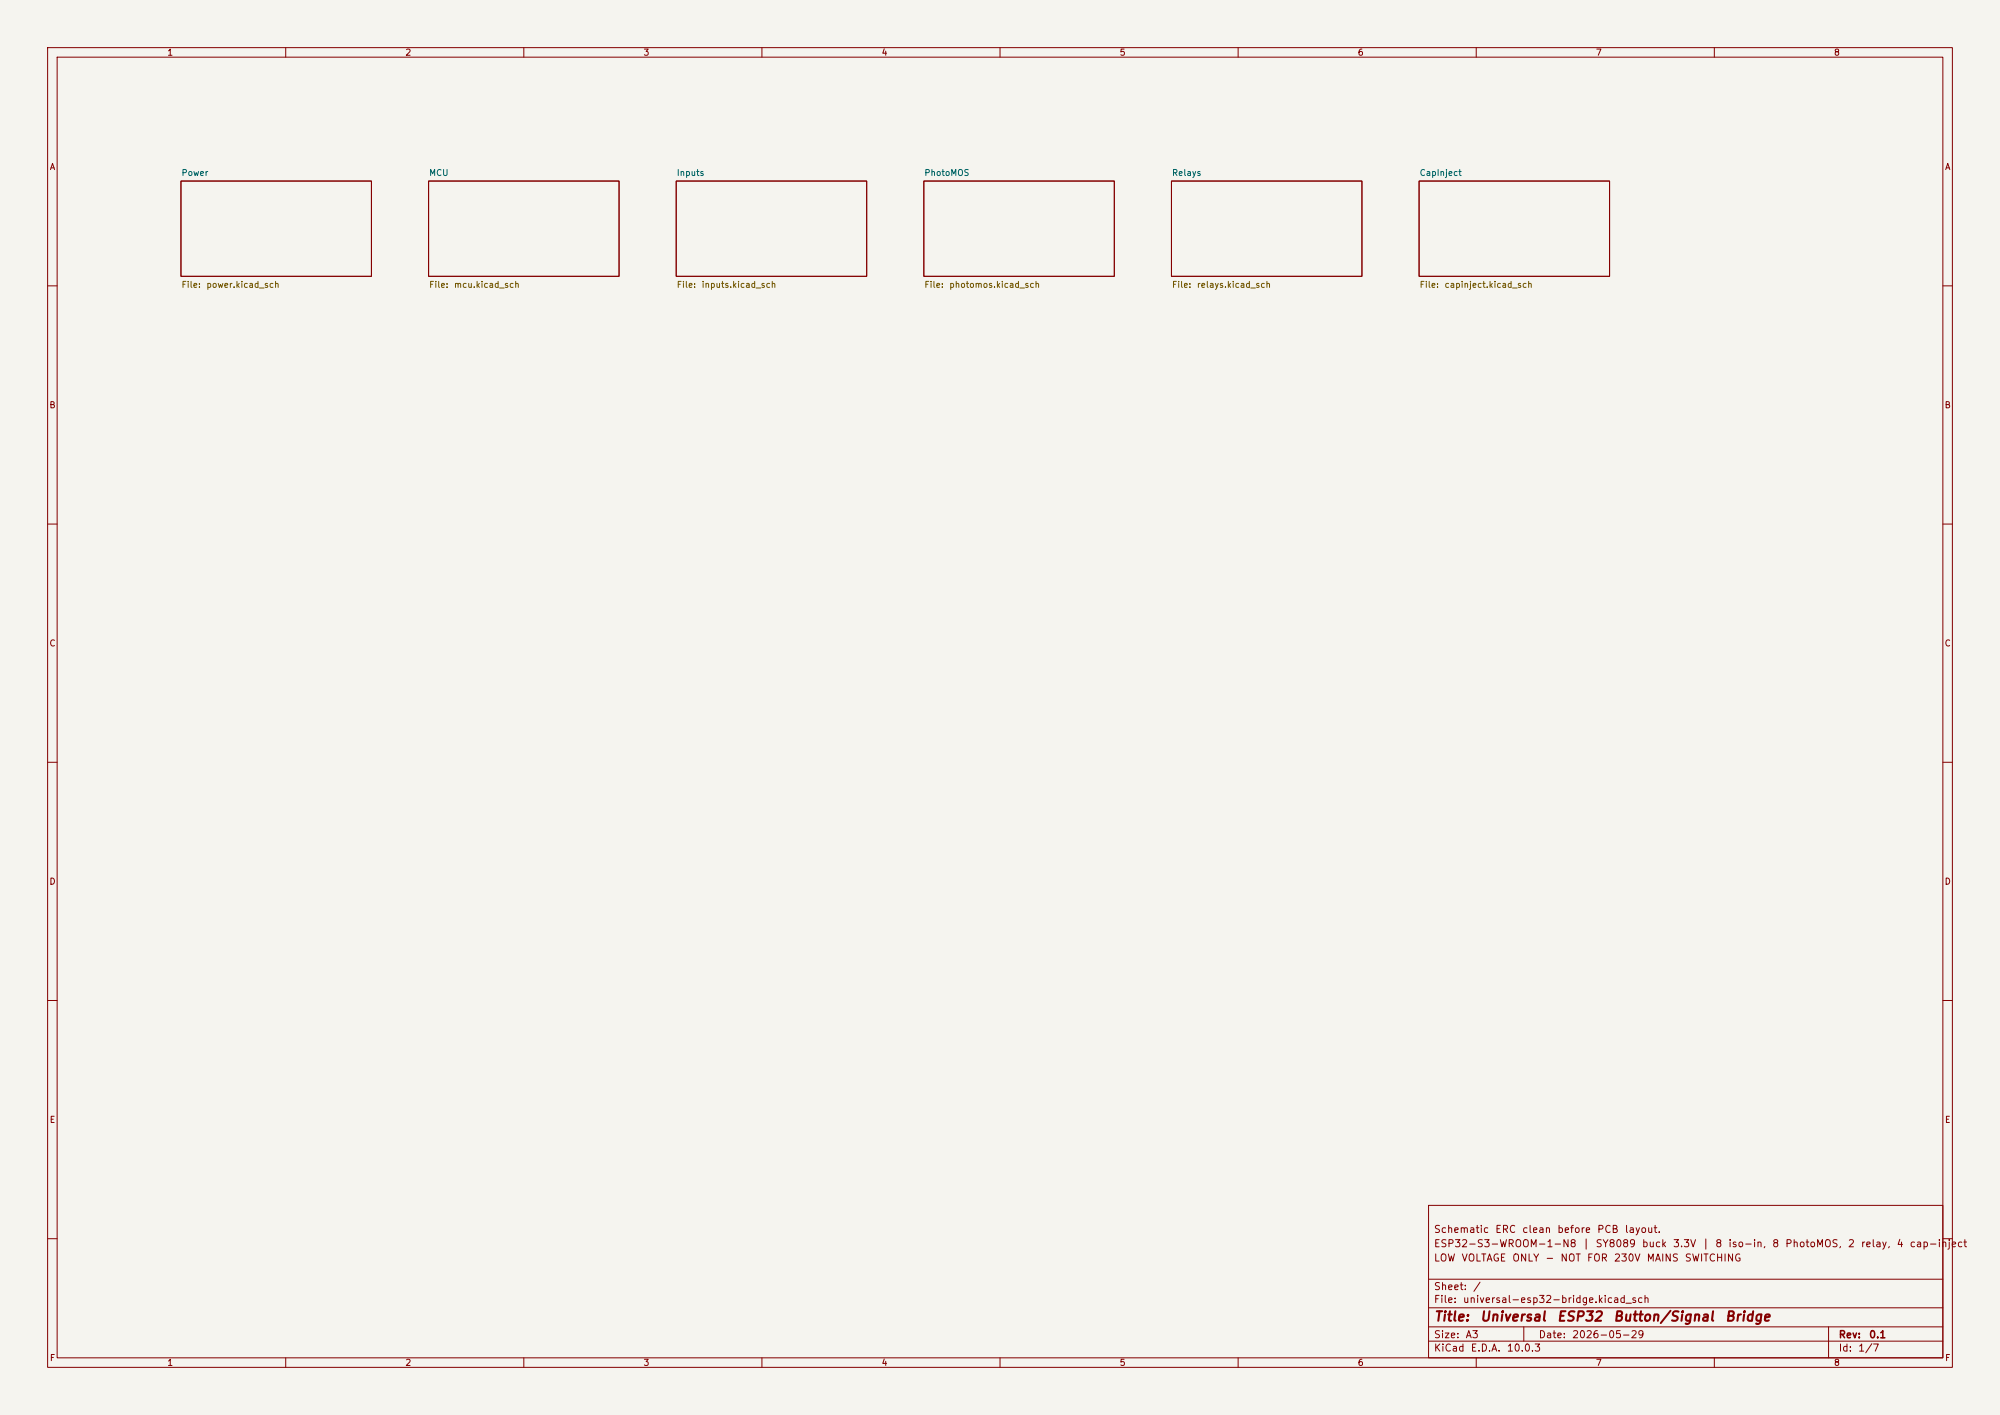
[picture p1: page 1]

Schematic ERC clean before PCB layout.
ESP32-S3-WROOM-1-N8 | SY8089 buck 3.3V | 8 iso-in, 8 PhotoMOS, 2 relay, 4 cap-inject
LOW VOLTAGE ONLY - NOT FOR 230V MAINS SWITCHING

Sheet: /
File: universal-esp32-bridge.kicad_sch
Title: Universal ESP32 Button/Signal Bridge

Size: A3 | Rev: 0.1
KiCad E.D.A. 10.0.3 | Id: 1/7 | F Date: 2026-05-29

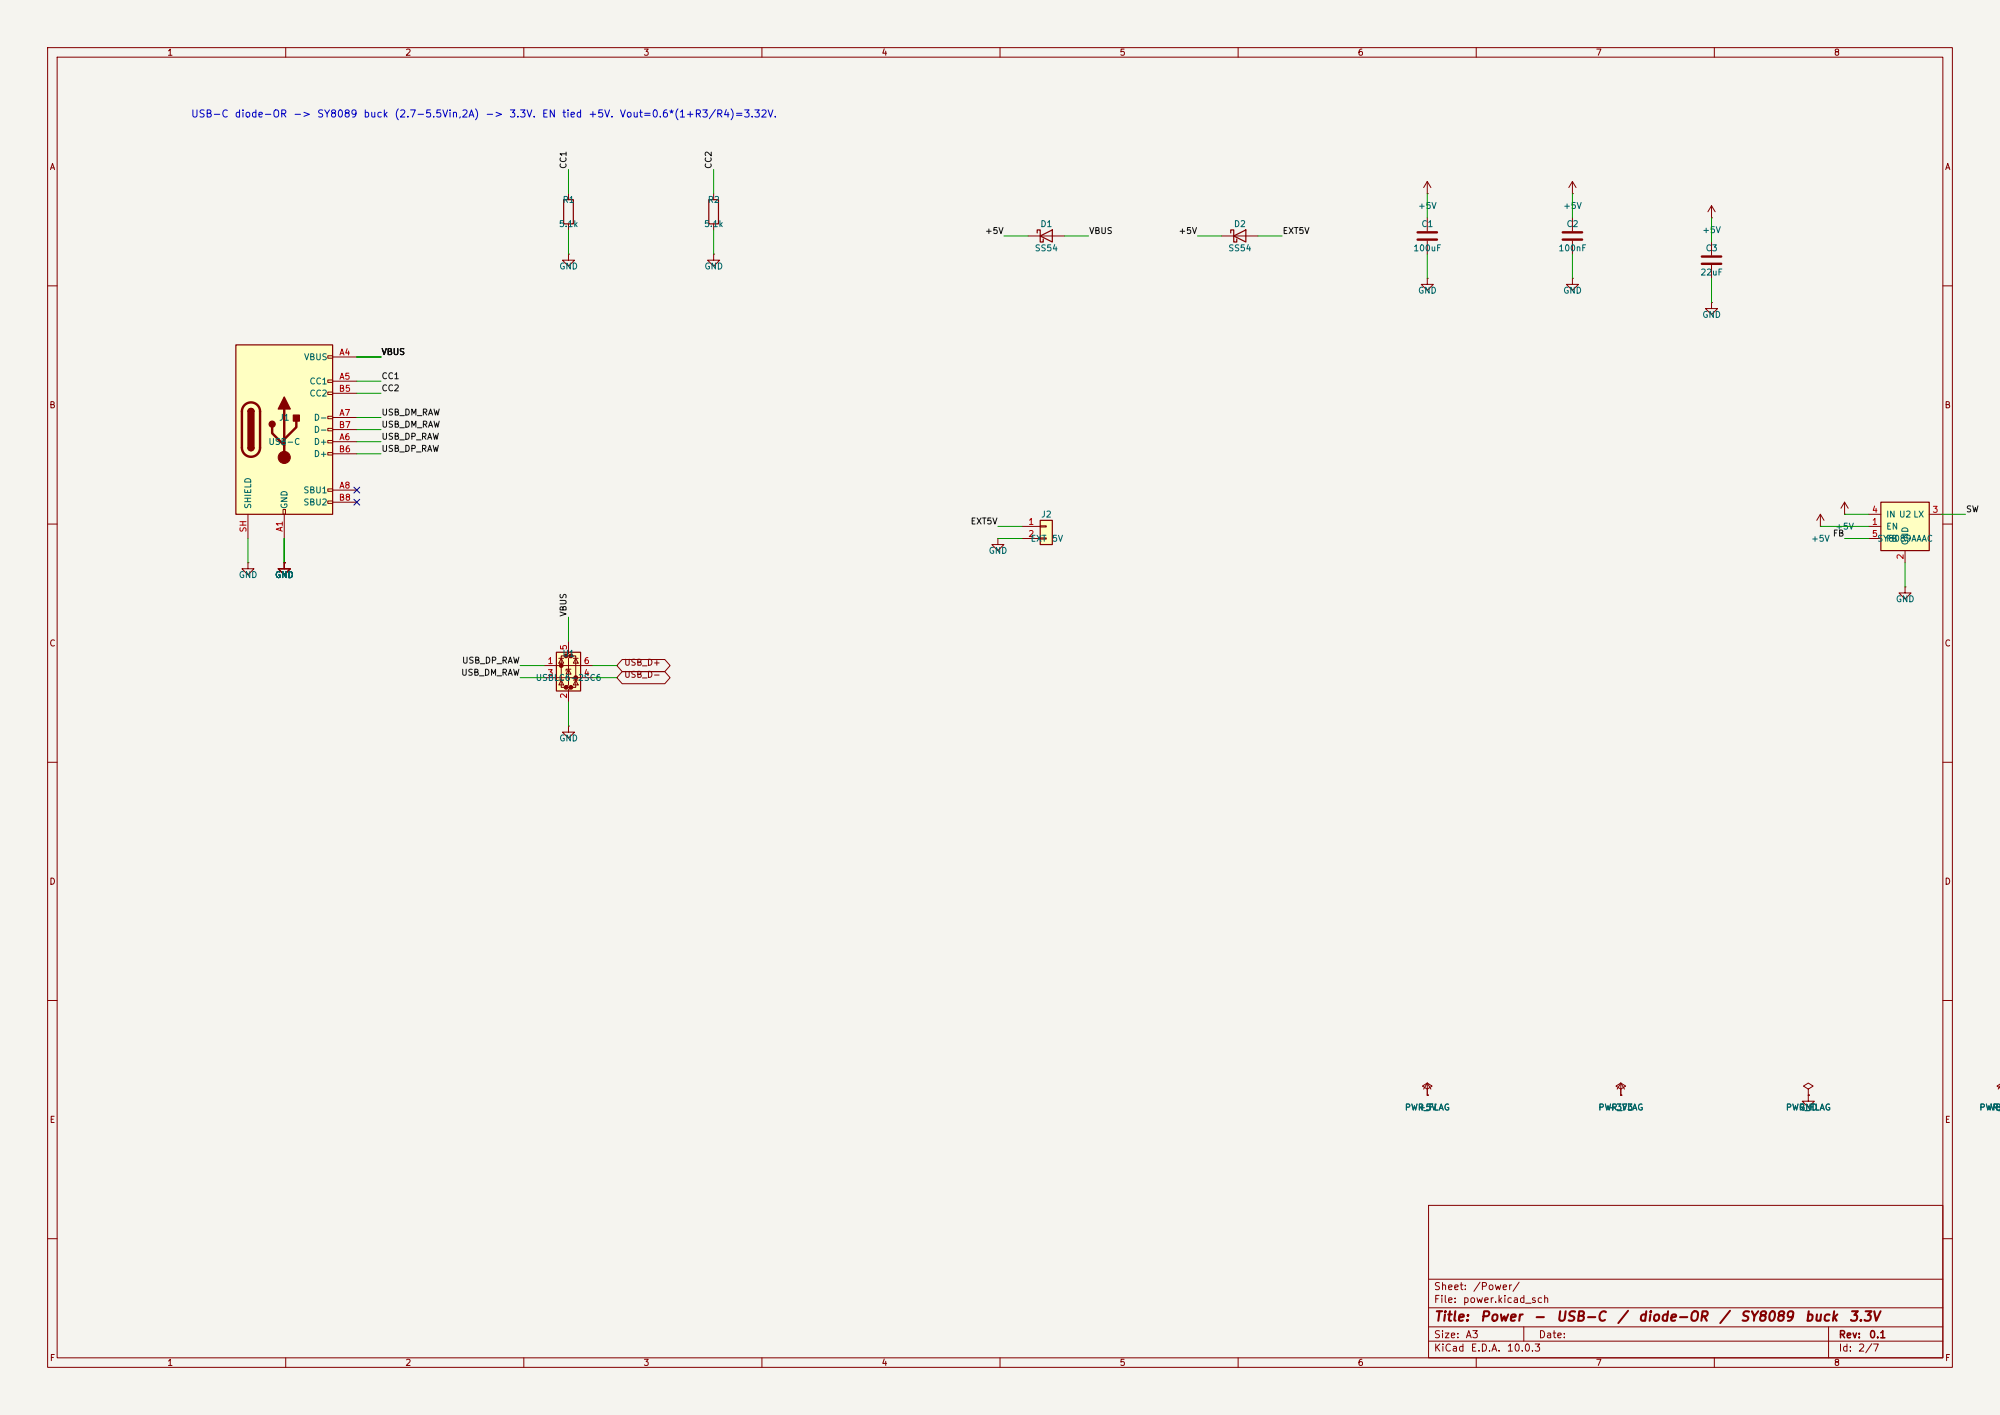
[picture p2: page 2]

SW USB-C diode-OR -> SY8089 buck (2.7-5.5Vin,2A) -> 3.3V. EN tied +5V. Vout=0.6*(1+R3/R4)=3.32V. GND

Sheet: /Power/
File: power.kicad_sch
Title: Power - USB-C / diode-OR / SY8089 buck 3.3V

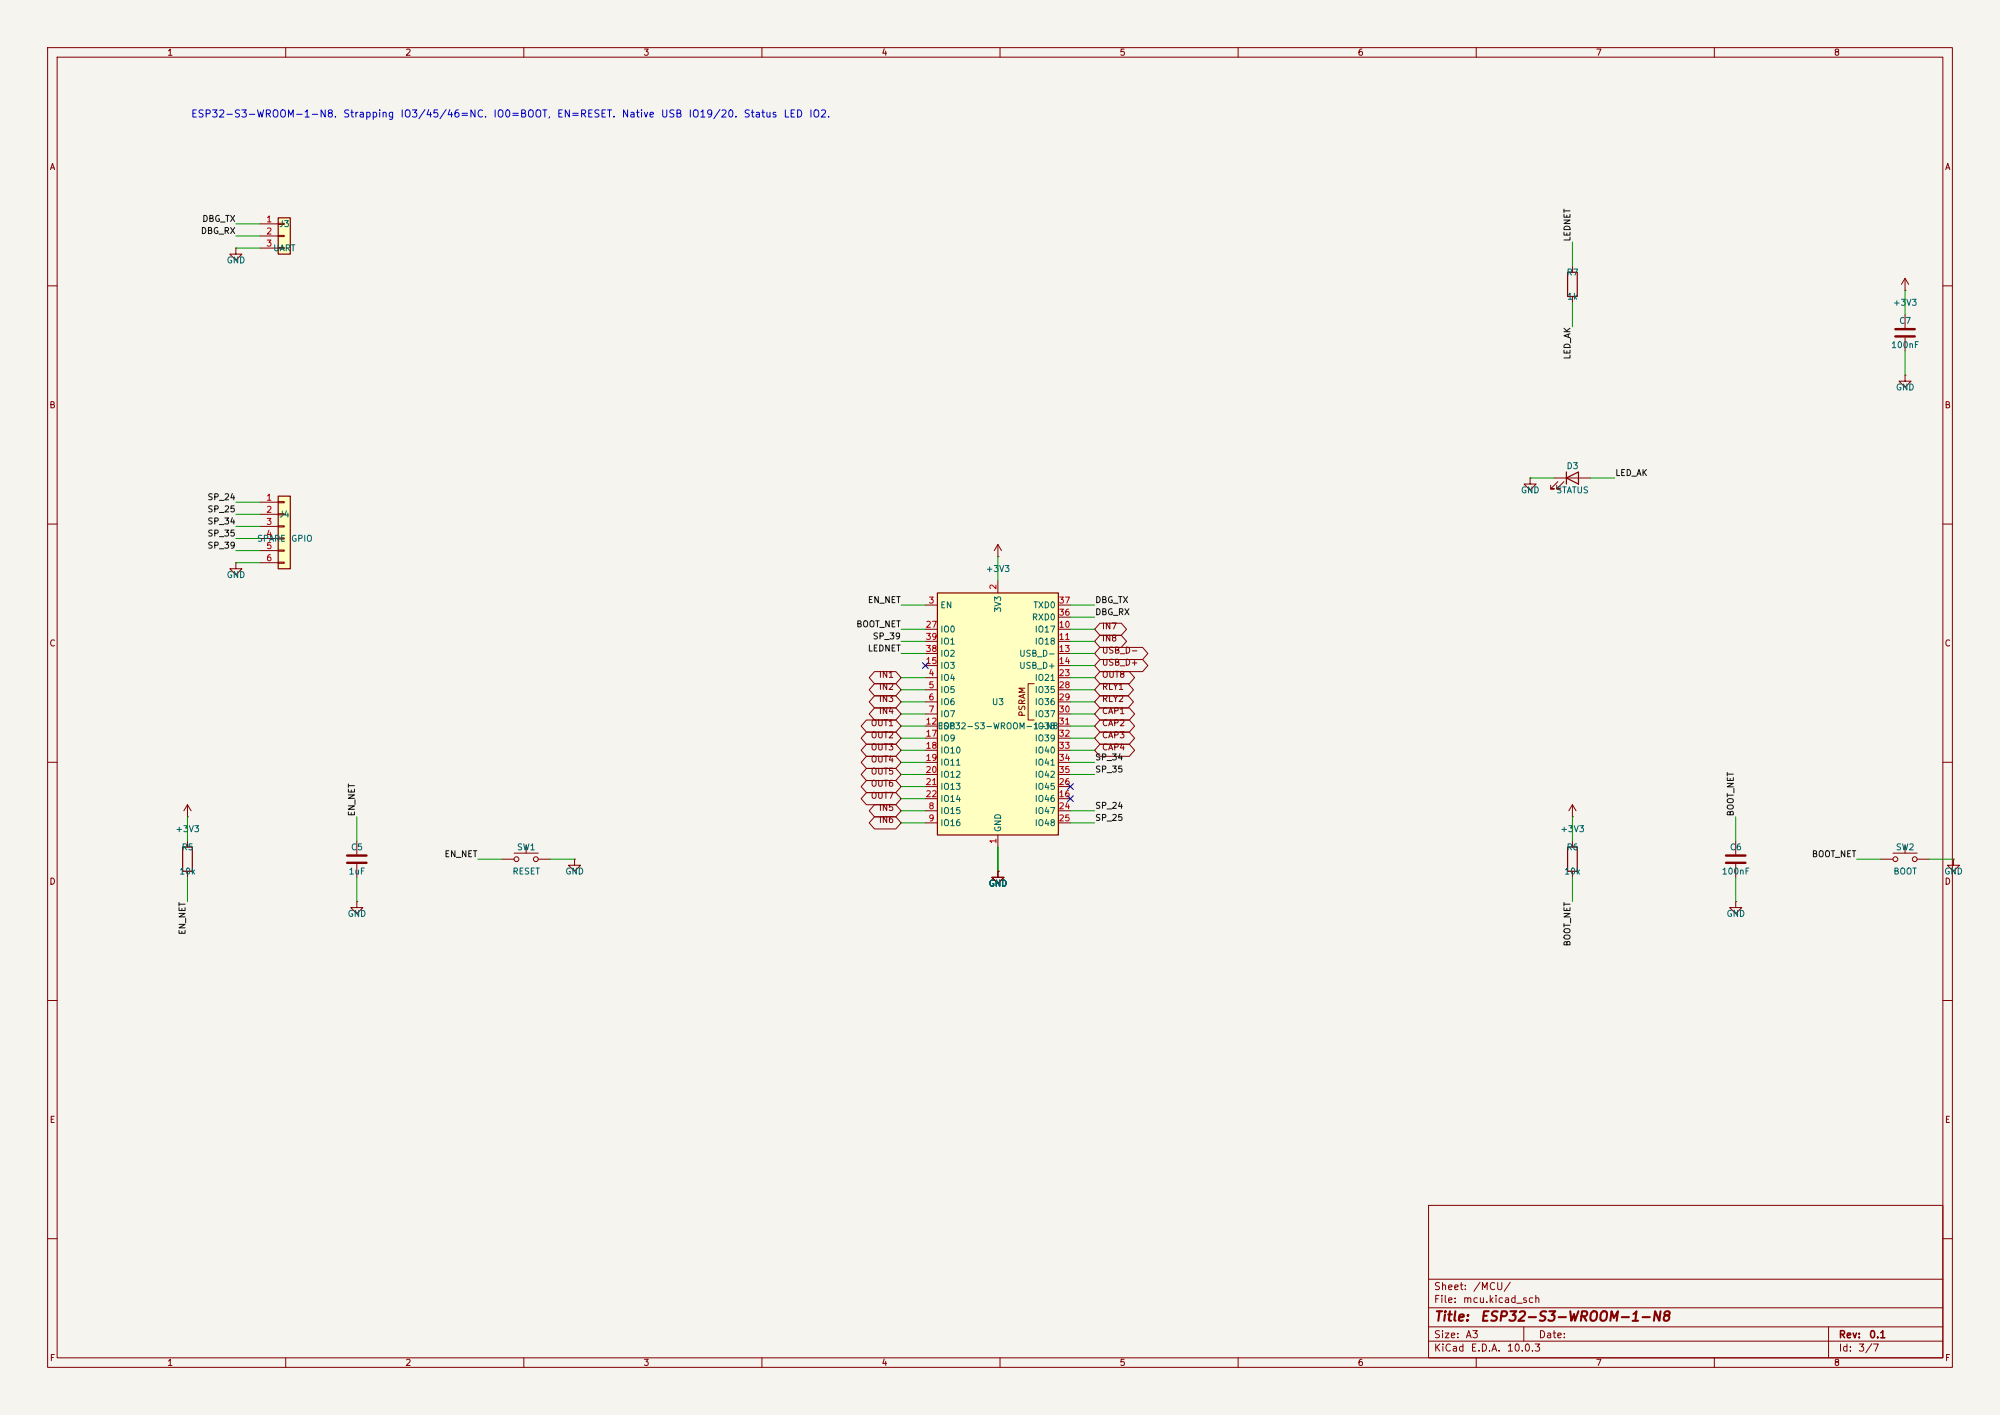
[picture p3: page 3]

ESP32-S3-WROOM-1-N8. Strapping IO3/45/46=NC. IO0=BOOT, EN=RESET. Native USB IO19/20. Status LED IO2.

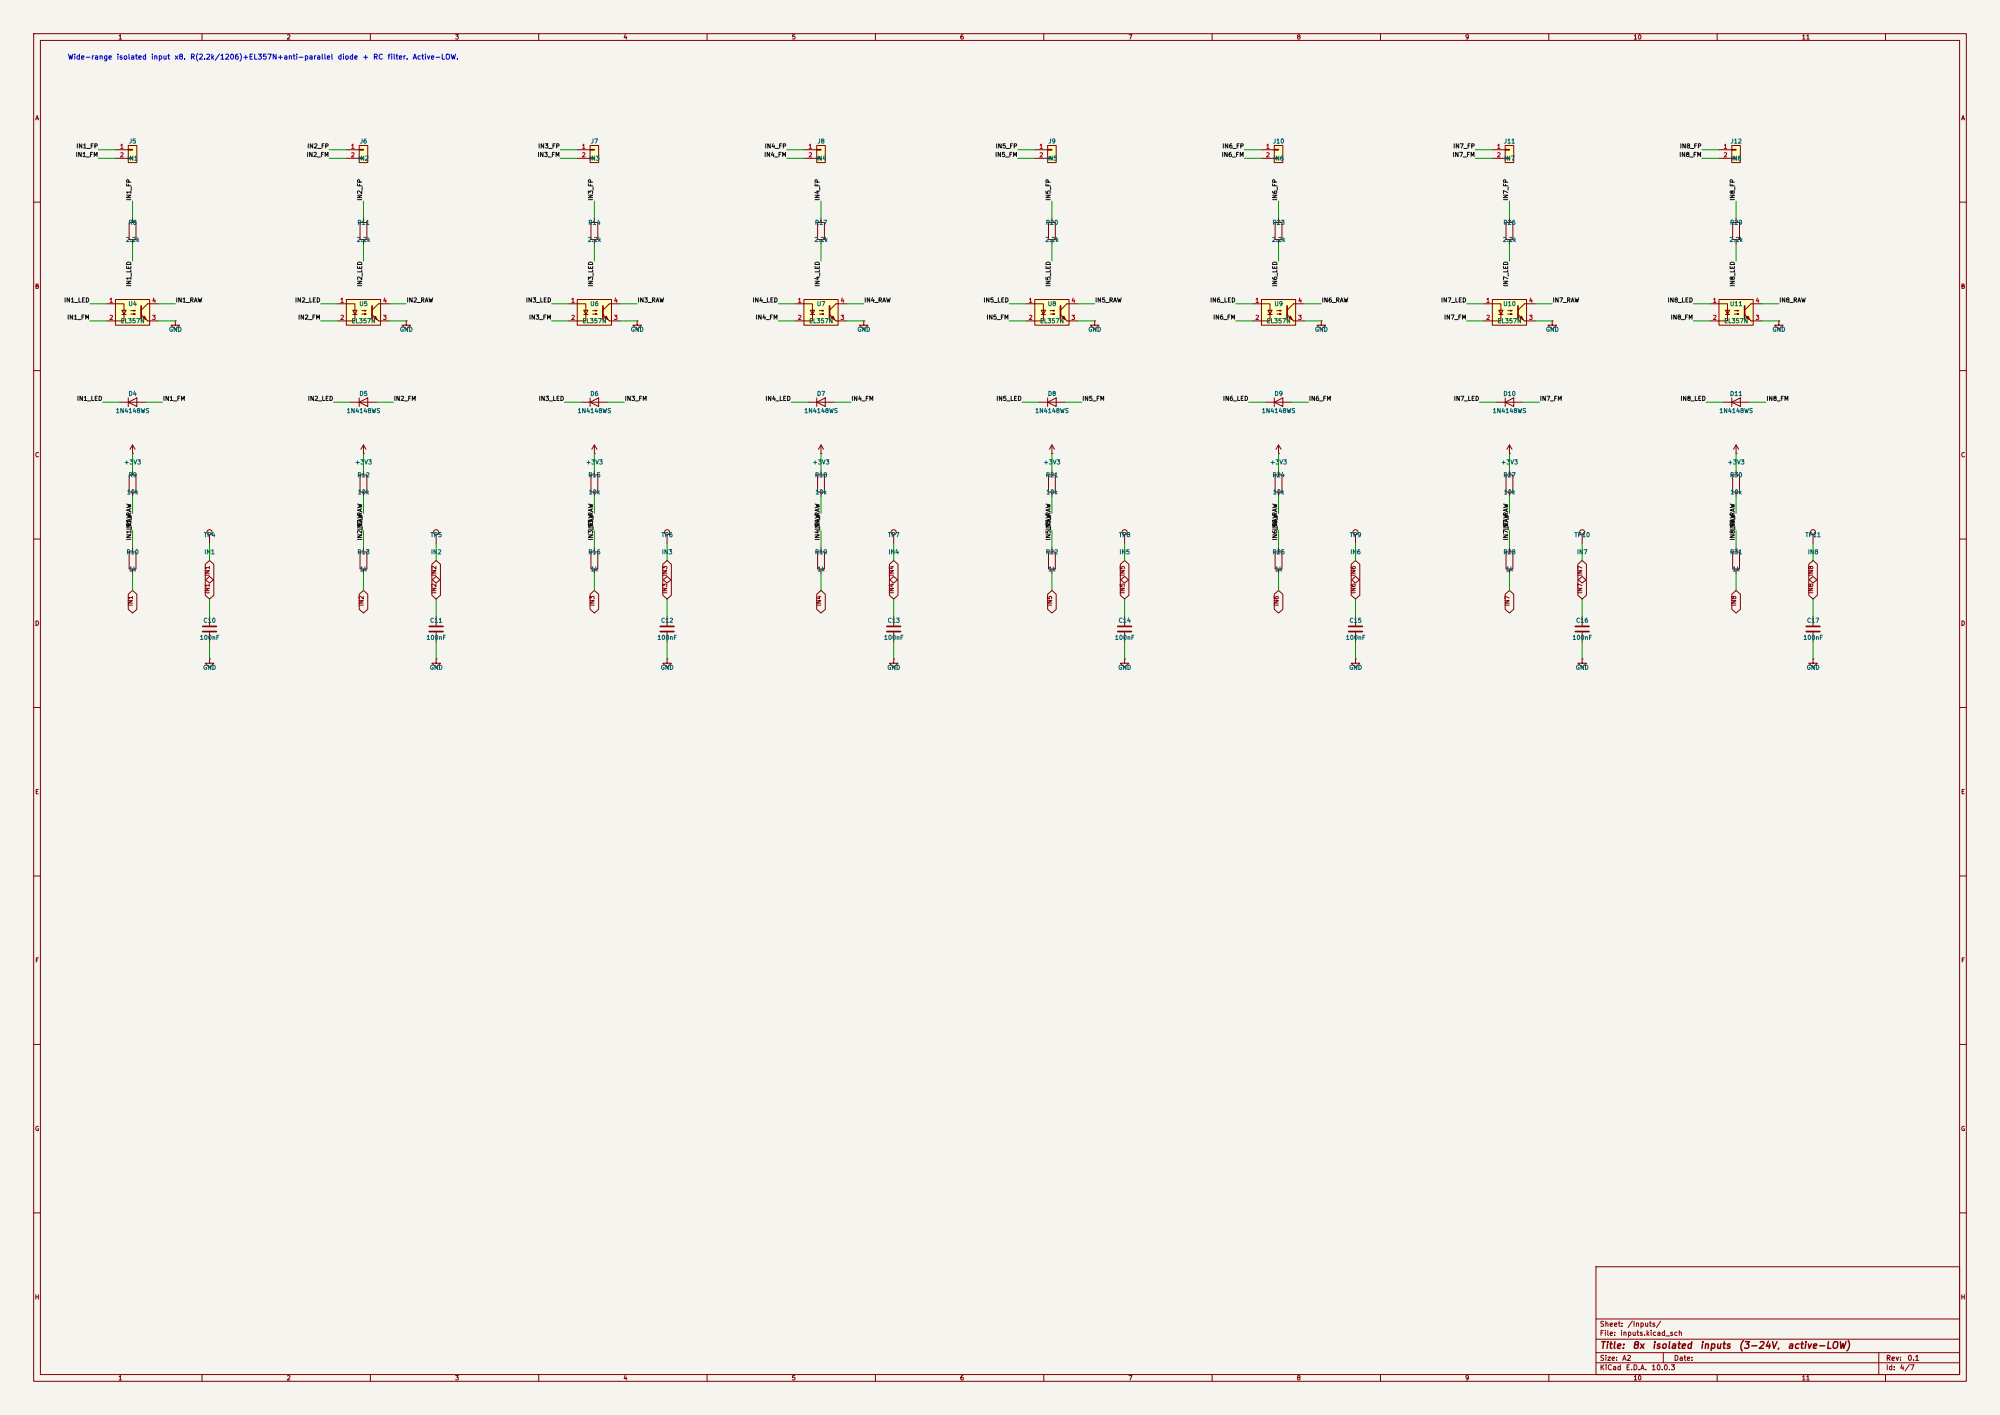
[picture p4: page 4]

IN6_LED Wide-range isolated input x8. R(2.2k/1206)+EL357N+anti-parallel diode + RC filter. Active-LOW.

Sheet: /Inputs/
File: inputs.kicad_sch
Title: 8x isolated inputs (3-24V, active-LOW)

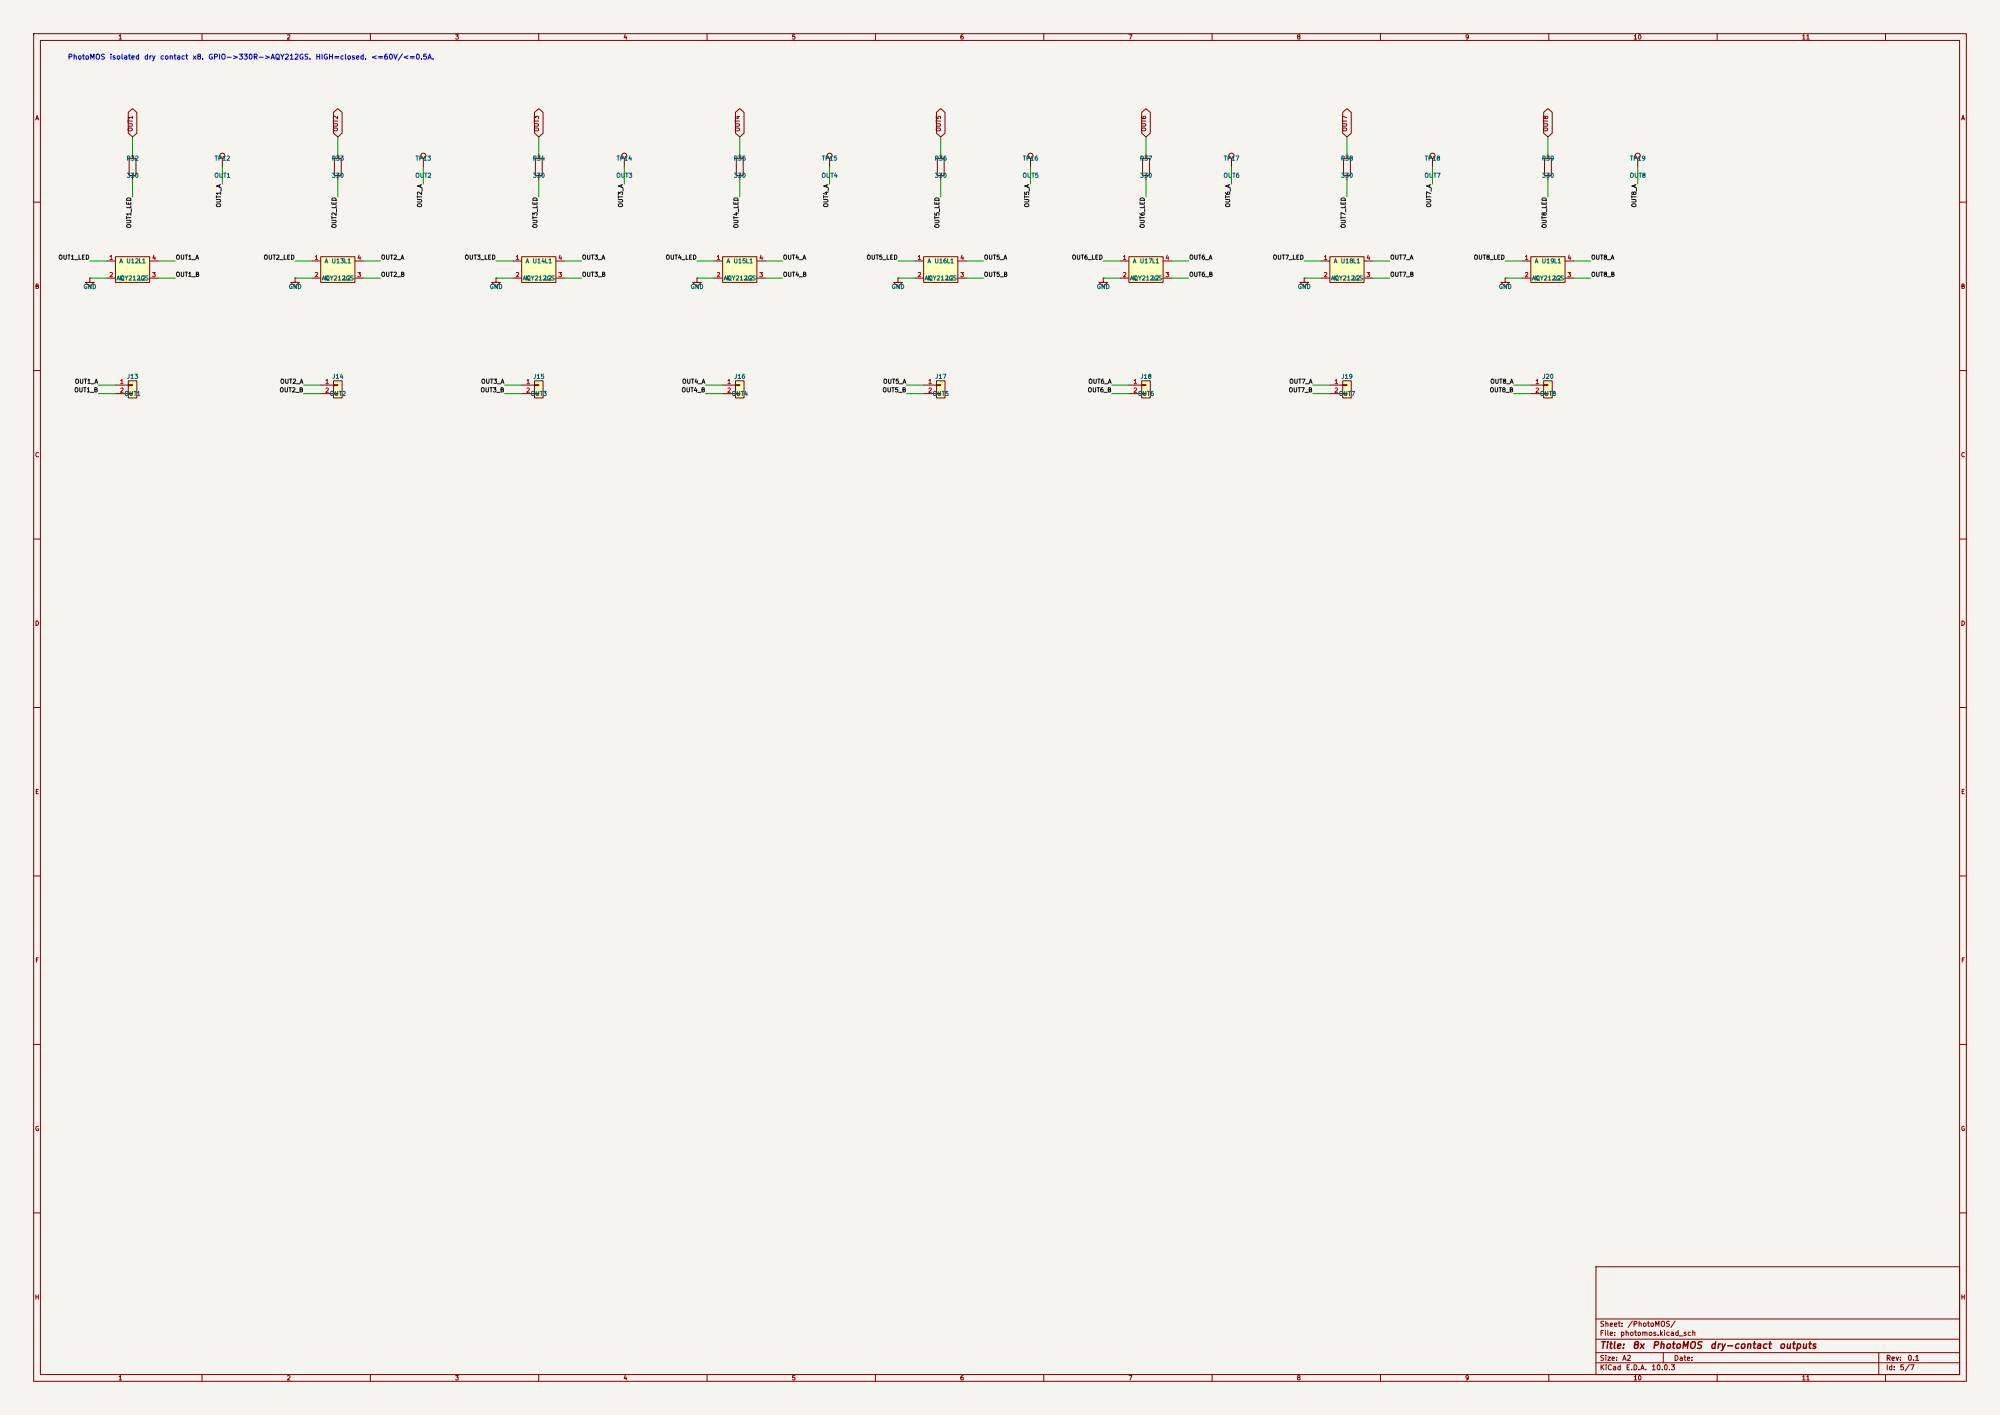
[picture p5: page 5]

Sheet: /PhotoMOS/
File: photomos.kicad_sch
Title: 8x PhotoMOS dry-contact outputs

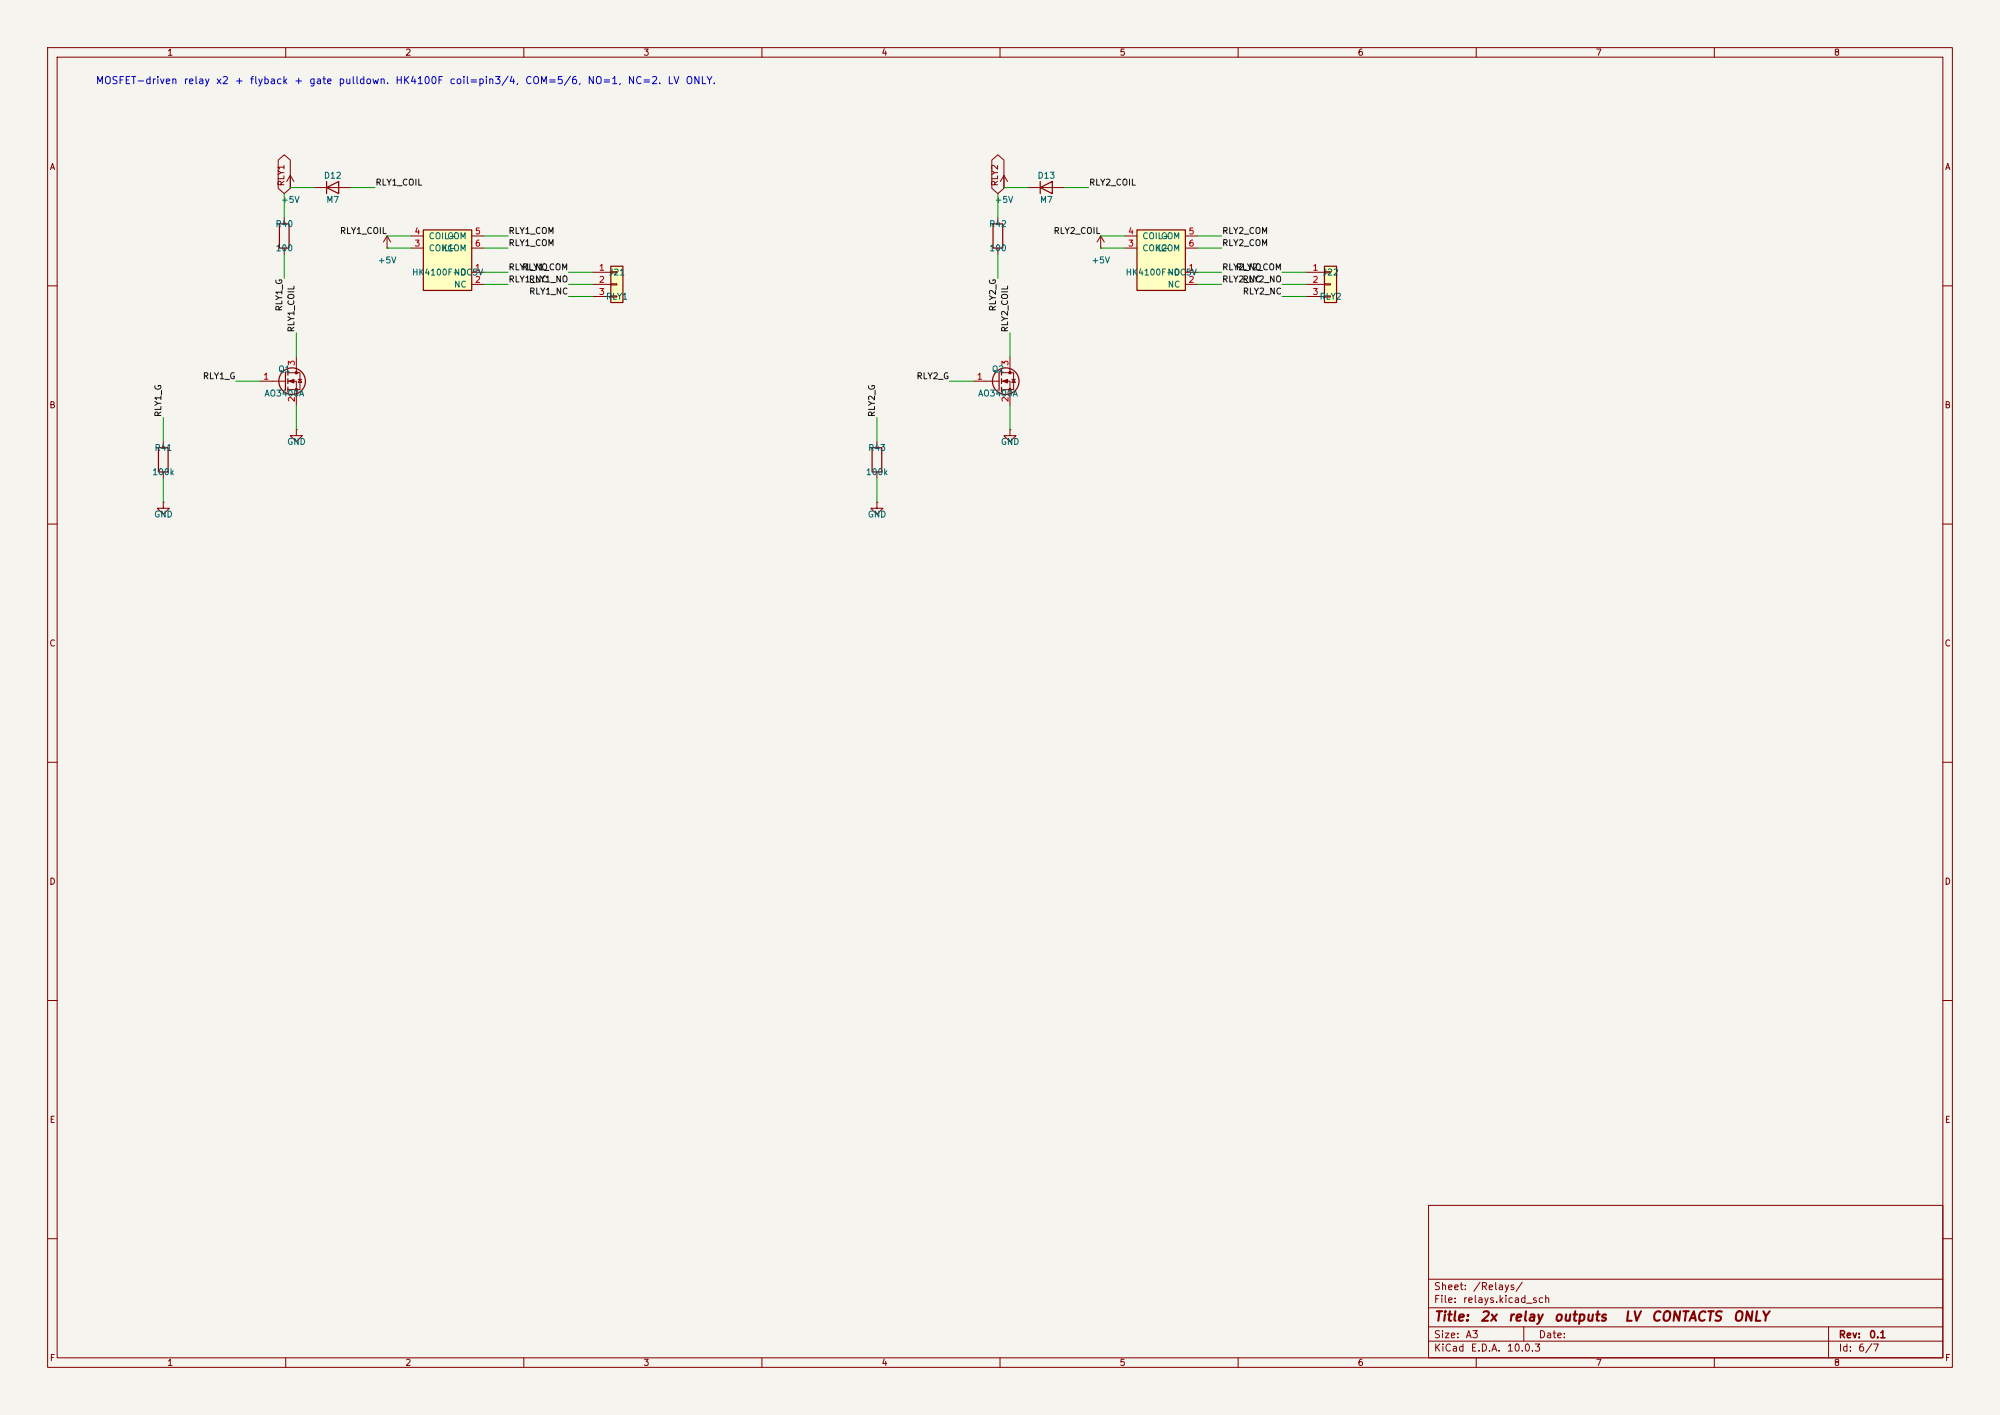
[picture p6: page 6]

RLY2_NO MOSFET-driven relay x2 + flyback + gate pulldown. HK4100F coil=pin3/4, COM=5/6, NO=1, NC=2. LV ONLY.

Sheet: /Relays/
File: relays.kicad_sch
Title: 2x relay outputs LV CONTACTS ONLY

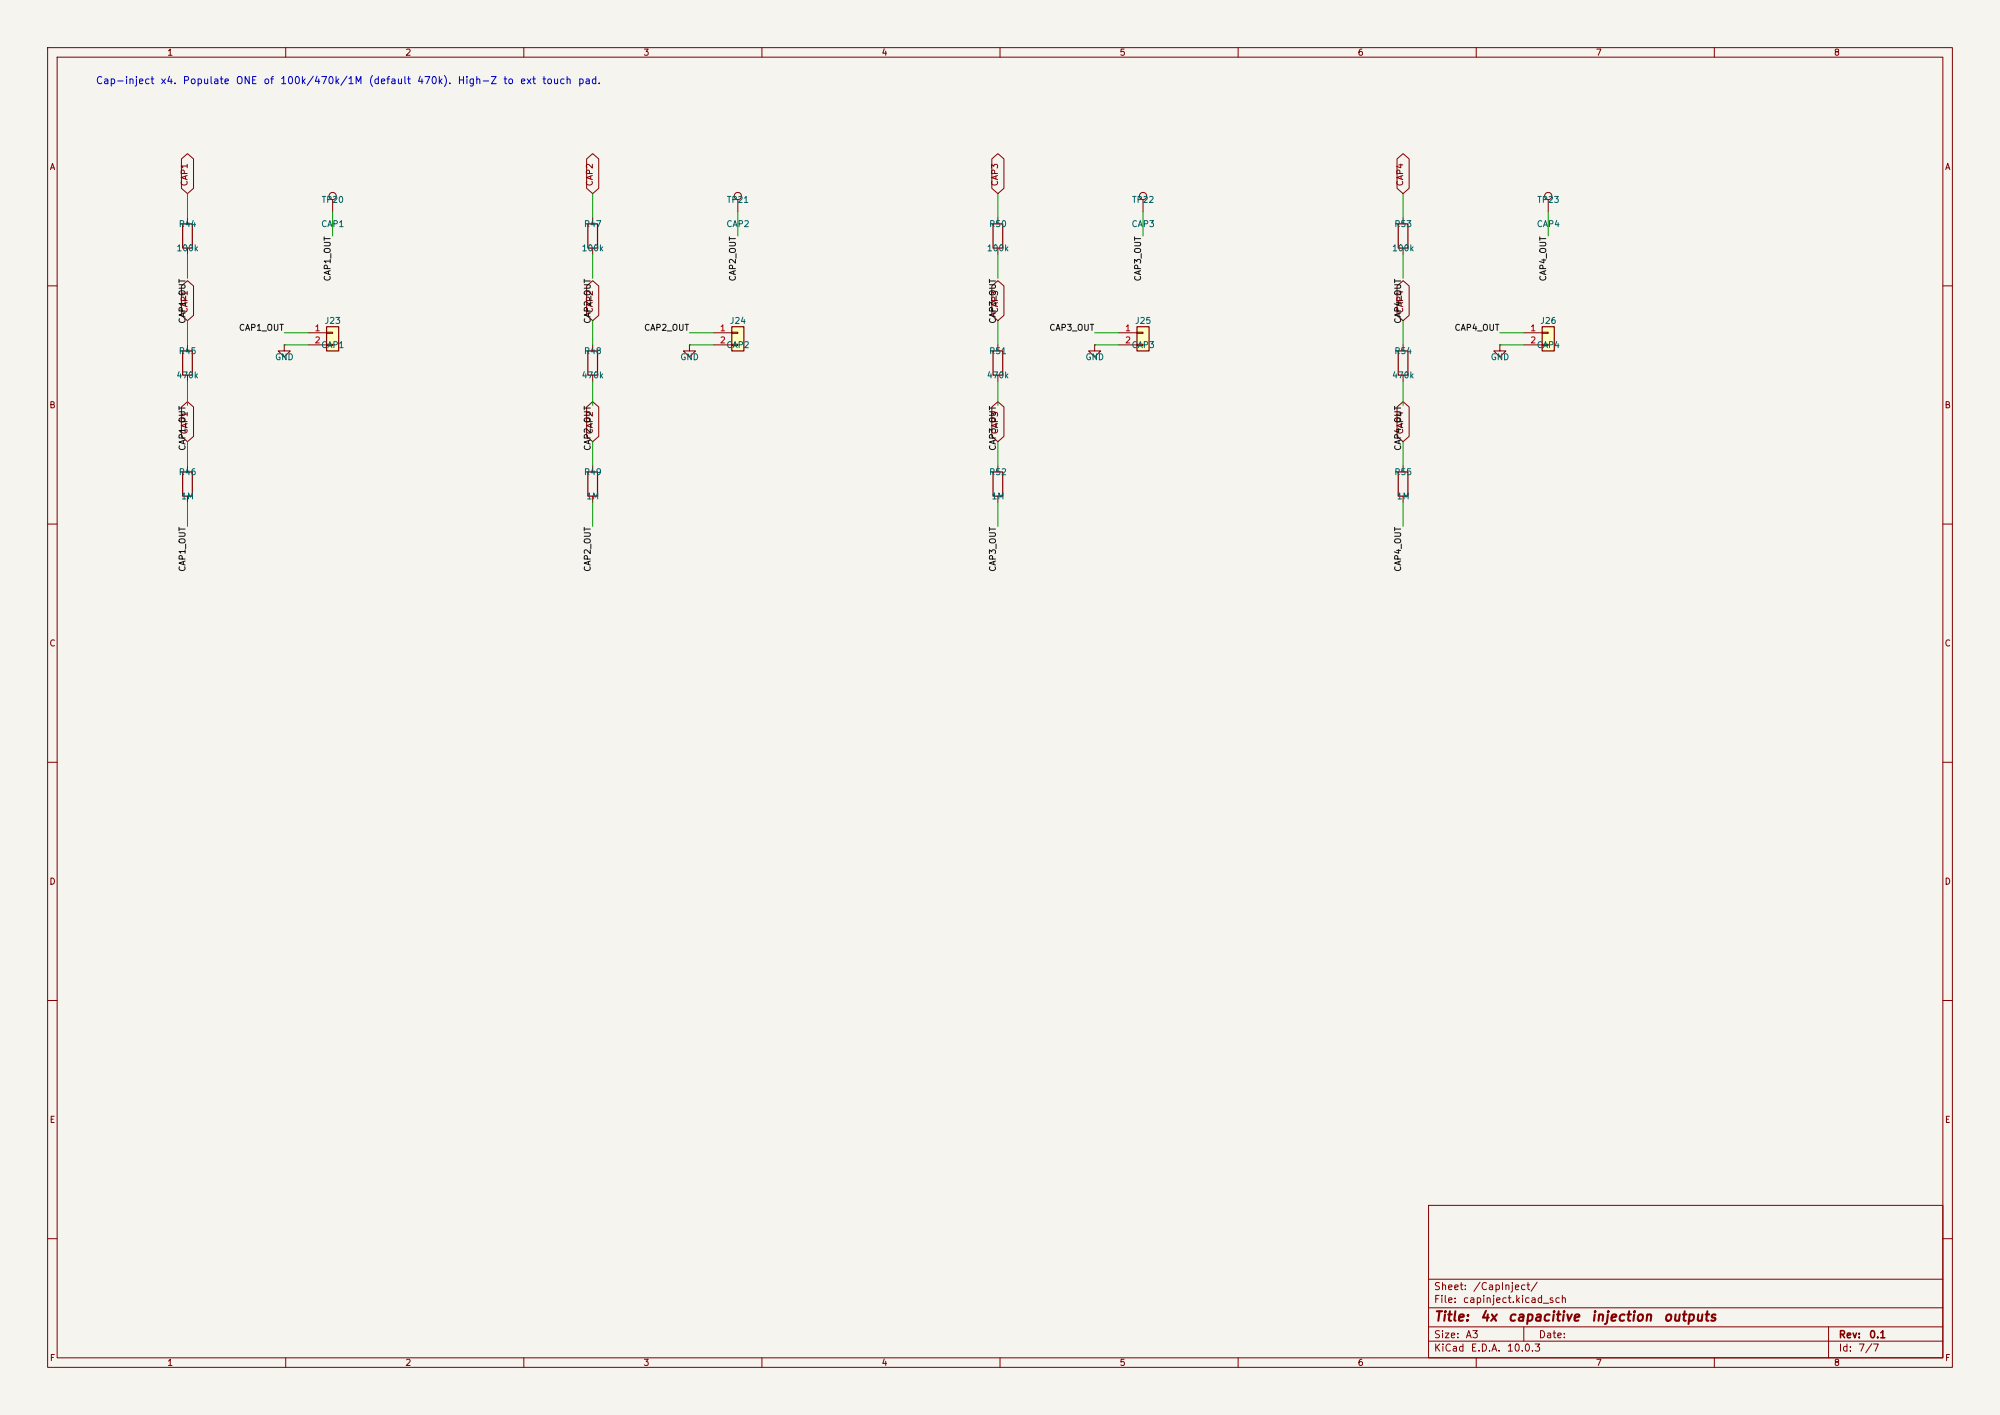
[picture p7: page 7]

Cap-inject x4. Populate ONE of 100k/470k/1M (default 470k). High-Z to ext touch pad.

Sheet: /CapInject/
File: capinject.kicad_sch
Title: 4x capacitive injection outputs

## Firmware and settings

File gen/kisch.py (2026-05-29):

"""Minimal KiCad 10 schematic generator.

Strategy for ERC-clean connectivity WITHOUT fragile wire geometry:
- Place each symbol at a known origin, rotation 0, no mirror.
- Compute each pin's absolute endpoint from the library pin (at x y angle).
- Connect nets by placing a LABEL (local / hierarchical) or a POWER symbol
  exactly at the pin endpoint. KiCad nets a label/power-pin that shares a
  coordinate with a component pin -> no wires needed, geometry is exact.

This module only needs correct pin-endpoint math, which we validate with
`kicad-cli sch erc` on a trivial circuit before scaling up.
"""
import re, uuid, os, itertools

SYMDIR = "/Applications/KiCad/KiCad.app/Contents/SharedSupport/symbols"

# ---------- tiny S-expression reader ----------
def tokenize(s):
    out, i, n = [], 0, len(s)
    while i < n:
        c = s[i]
        if c in ' \t\r\n':
            i += 1
        elif c == '(':
            out.append('('); i += 1
        elif c == ')':
            out.append(')'); i += 1
        elif c == '"':
            j = i + 1; buf = []
            while j < n:
                if s[j] == '\\':
                    buf.append(s[j+1]); j += 2
                elif s[j] == '"':
                    break
                else:
                    buf.append(s[j]); j += 1
            out.append(('str', ''.join(buf))); i = j + 1
        else:
            j = i
            while j < n and s[j] not in ' \t\r\n()"':
                j += 1
            out.append(('atom', s[i:j])); i = j
    return out

def parse(tokens):
    # returns nested lists; atoms as ('atom',v) or ('str',v)
    pos = 0
    def rd():
        nonlocal pos
        t = tokens[pos]; pos += 1
        if t == '(':
            lst = []
            while tokens[pos] != ')':
                lst.append(rd())
            pos += 1
            return lst
        return t
    nodes = []
    while pos < len(tokens):
        nodes.append(rd())
    return nodes

CUSTOM_LIBS = {}  # libname -> absolute path of a .kicad_sym

def load_lib(libname):
    if libname in CUSTOM_LIBS:
        path = CUSTOM_LIBS[libname]
    else:
        path = os.path.join(SYMDIR, libname + ".kicad_sym")
    with open(path) as f:
        return f.read()

# ---------- raw symbol-block text extraction (balanced parens) ----------
def extract_symbol_block(text, name):
    """Return the raw text of (symbol "name" ...) top-level block."""
    needle = '(symbol "%s"' % name
    start = text.find(needle)
    if start < 0:
        raise KeyError("symbol %r not found" % name)
    depth = 0; i = start
    while i < len(text):
        if text[i] == '(':
            depth += 1
        elif text[i] == ')':
            depth -= 1
            if depth == 0:
                return text[start:i+1]
        i += 1
    raise ValueError("unbalanced")

def pins_of(text, name):
    """Parse pins of a library symbol: list of dict(number,name,x,y,angle).
    Pins live inside child units (symbol "name_u_v" ...)."""
    block = extract_symbol_block(text, name)
    nodes = parse(tokenize(block))[0]  # the (symbol ...) list
    pins = []
    def walk(node):
        if not isinstance(node, list):
            return
        if node and node[0] == ('atom', 'pin'):
            x=y=ang=None; num=nm=None
            for c in node:
                if isinstance(c, list) and c and c[0]==('atom','at'):
                    x=float(c[1][1]); y=float(c[2][1]); ang=float(c[3][1])
                if isinstance(c, list) and c and c[0]==('atom','number'):
                    num=c[1][1]
                if isinstance(c, list) and c and c[0]==('atom','name'):
                    nm=c[1][1]
            pins.append(dict(number=num,name=nm,x=x,y=y,angle=ang))
        for c in node:
            walk(c)
    walk(nodes)
    return pins

def _uuid():
    return str(uuid.uuid4())

GRID=1.27
def snap(v):
    return round(round(v/GRID)*GRID, 2)
def snapxy(p):
    return (snap(p[0]), snap(p[1]))

FPDIR="/Applications/KiCad/KiCad.app/Contents/SharedSupport/footprints"

_pwr_ctr=itertools.count(1)
def _pwr_ref():
    return "#PWR%03d"%next(_pwr_ctr)

class Comp:
    def __init__(self, lib_id, ref, value, at, pinmap, mirror=None):
        self.lib_id=lib_id; self.ref=ref; self.value=value
        self.x, self.y = snap(at[0]), snap(at[1]); self.pinmap=pinmap  # number -> (px,py)
        self.uuid=_uuid(); self.fields={}; self.mirror=mirror
        self.unit=1
    def pin(self, number):
        px, py = self.pinmap[str(number)][:2]
        # rotation 0; lib +Y up -> sch +Y down
        return (round(self.x+px,4), round(self.y-py,4))
    def outdir(self, number):
        # outward direction (away from body) from the pin's orientation angle
        a = int(self.pinmap[str(number)][2]) % 360
        return {0:'L', 180:'R', 90:'D', 270:'U'}.get(a, 'R')

class Sheet:
    """A child schematic file."""
    def __init__(self, proj, name, filename, title):
        self.proj=proj; self.name=name; self.filename=filename; self.title=title
        self.file_uuid=_uuid()      # the (uuid) of this file
        self.inst_uuid=_uuid()      # uuid of the (sheet) object placed on root
        self.page="?"; self.paper="A3"
        self.comps=[]; self.labels=[]; self.powers=[]; self.wires=[]
        self.glabels=[]; self.ncs=[]; self.texts=[]
        self._refs={}
    # ---- placement ----
    def place(self, lib, name, ref, value, at, footprint=None, fields=None, mirror=None):
        libtext = self.proj.lib(lib)
        pins = pins_of(libtext, name)
        pinmap = {p['number']:(p['x'],p['y'],p['angle']) for p in pins}
        c = Comp("%s:%s"%(lib,name), ref, value, at, pinmap, mirror)
        if footprint: c.fields['Footprint']=footprint
        if fields: c.fields.update(fields)
        self.proj.use_symbol(lib, name)
        self.comps.append(c); return c
    def power(self, sym, at):  # sym in power lib: GND,+3V3,+5V,PWR_FLAG,VBUS...
        self.proj.use_symbol('power', sym)
        pins = pins_of(self.proj.lib('power'), sym)
        pinmap={p['number']:(p['x'],p['y'],p['angle']) for p in pins}
        c=Comp("power:%s"%sym, _pwr_ref(), sym, at, pinmap)
        c.is_power=True
        self.powers.append(c); return c
    def label(self, text, at, angle=0):
        self.labels.append((text, snap(at[0]), snap(at[1]), angle))
    def glabel(self, text, at, angle=0, shape="bidirectional"):
        self.glabels.append((text, snap(at[0]), snap(at[1]), angle, shape))
    def wire(self, p1, p2):
        self.wires.append((snapxy(p1),snapxy(p2)))
    def nc(self, at):
        self.ncs.append(snapxy(at))
    def text(self, s, at, size=1.5):
        self.texts.append((s, at[0], at[1], size))

class Project:
    def __init__(self, name, outdir):
        self.name=name; self.outdir=outdir
        self.root_uuid=_uuid()
        self.sheets=[]
        self._libcache={}
        self._used={}  # lib -> set(names) for lib_symbols emission
        self.root_powers=[]; self.root_texts=[]
    def lib(self, libname):
        if libname not in self._libcache:
            self._libcache[libname]=load_lib(libname)
        return self._libcache[libname]
    def use_symbol(self, lib, name):
        self._used.setdefault(lib,set()).add(name)
    def add_sheet(self, name, filename, title):
        s=Sheet(self, name, filename, title); self.sheets.append(s)
        s.page=str(len(self.sheets)+1)  # root is page 1
        return s
    # ---- emit helpers ----
    def _lib_symbols_block(self):
        out=["\t(lib_symbols"]
        for lib in sorted(self._used):
            t=self.lib(lib)
            for name in sorted(self._used[lib]):
                block=extract_symbol_block(t, name)
                # rename top symbol id to lib:name
                block=block.replace('(symbol "%s"'%name, '(symbol "%s:%s"'%(lib,name),1)
                # indent
                block="\n".join("\t\t"+ln if ln.strip() else ln for ln in block.split("\n"))
                out.append(block)
        out.append("\t)")
        return "\n".join(out)
    def _prop(self, name, val, x, y, hide=False, angle=0):
        h="\n\t\t\t\t(hide yes)" if hide else ""
        v=val.replace('\\','\\\\').replace('"','\\"')
        return ('\t\t(property "%s" "%s"\n\t\t\t(at %s %s %s)\n\t\t\t(effects\n\t\t\t\t(font\n\t\t\t\t\t(size 1.27 1.27)\n\t\t\t\t)%s\n\t\t\t)\n\t\t)'
                %(name,v,x,y,angle,h))
    def _comp_block(self, c, sheet, path):
        lines=["\t(symbol",'\t\t(lib_id "%s")'%c.lib_id, "\t\t(at %s %s 0)"%(c.x,c.y)]
        if c.mirror: lines.append("\t\t(mirror %s)"%c.mirror)
        lines+=["\t\t(unit 1)","\t\t(exclude_from_sim no)","\t\t(in_bom yes)","\t\t(on_board yes)","\t\t(dnp no)",
                '\t\t(uuid "%s")'%c.uuid]
        # properties
        refy=c.y-2.54; valy=c.y+2.54
        is_pwr=getattr(c,'is_power',False)
        lines.append(self._prop("Reference", c.ref, c.x, refy, hide=is_pwr))
        lines.append(self._prop("Value", c.value, c.x, valy, hide=False))
        lines.append(self._prop("Footprint", c.fields.get('Footprint',''), c.x, c.y, hide=True))
        lines.append(self._prop("Datasheet", c.fields.get('Datasheet','~'), c.x, c.y, hide=True))
        for k,v in c.fields.items():
            if k in ('Footprint','Datasheet'): continue
            lines.append(self._prop(k, v, c.x, c.y, hide=True))
        # pins
        for num in sorted(c.pinmap):
            lines.append('\t\t(pin "%s"\n\t\t\t(uuid "%s")\n\t\t)'%(num,_uuid()))
        # instances
        ref=c.ref
        lines.append('\t\t(instances\n\t\t\t(project "%s"\n\t\t\t\t(path "%s"\n\t\t\t\t\t(reference "%s")\n\t\t\t\t\t(unit 1)\n\t\t\t\t)\n\t\t\t)\n\t\t)'%(self.name,path,ref))
        lines.append("\t)")
        return "\n".join(lines)
    def _label_block(self, text,x,y,angle, kind="label", shape=None):
        j="left" if angle in (0,90) else "right"
        sh="\n\t\t(shape %s)"%shape if shape else ""
        return ('\t(%s "%s"\n\t\t(at %s %s %s)%s\n\t\t(effects\n\t\t\t(font\n\t\t\t\t(size 1.27 1.27)\n\t\t\t)\n\t\t\t(justify %s bottom)\n\t\t)\n\t\t(uuid "%s")\n\t)'
                %(kind,text,x,y,angle,sh,j,_uuid()))
    def _wire_block(self,p1,p2):
        return ('\t(wire\n\t\t(pts\n\t\t\t(xy %s %s) (xy %s %s)\n\t\t)\n\t\t(stroke\n\t\t\t(width 0)\n\t\t\t(type default)\n\t\t)\n\t\t(uuid "%s")\n\t)'%(p1[0],p1[1],p2[0],p2[1],_uuid()))
    def _nc_block(self,at):
        return '\t(no_connect\n\t\t(at %s %s)\n\t\t(uuid "%s")\n\t)'%(at[0],at[1],_uuid())
    def _text_block(self,s,x,y,size):
        s=s.replace('"','\\"')
        return '\t(text "%s"\n\t\t(exclude_from_sim no)\n\t\t(at %s %s 0)\n\t\t(effects\n\t\t\t(font\n\t\t\t\t(size %s %s)\n\t\t\t)\n\t\t\t(justify left bottom)\n\t\t)\n\t\t(uuid "%s")\n\t)'%(s,x,y,size,size,_uuid())
    def write_sheet(self, s):
        path="/%s/%s"%(self.root_uuid, s.inst_uuid)
        body=["(kicad_sch",'\t(version 20250114)','\t(generator "kisch")','\t(generator_version "10.0")',
              '\t(uuid "%s")'%s.file_uuid,'\t(paper "%s")'%s.paper,
              '\t(title_block\n\t\t(title "%s")\n\t\t(rev "0.1")\n\t)'%s.title,
              self._lib_symbols_block()]
        for t in s.texts: body.append(self._text_block(*t))
        for (text,x,y,a) in s.labels: body.append(self._label_block(text,x,y,a,"label"))
        for (text,x,y,a,shape) in s.glabels: body.append(self._label_block(text,x,y,a,"global_label",shape))
        for w in s.wires: body.append(self._wire_block(*w))
        for nc in s.ncs: body.append(self._nc_block(nc))
        for c in s.comps: body.append(self._comp_block(c,s,path))
        for c in s.powers: body.append(self._comp_block(c,s,path))
        body.append('\t(sheet_instances\n\t\t(path "/"\n\t\t\t(page "%s")\n\t\t)\n\t)'%s.page)
        body.append(")")
        open(os.path.join(self.outdir,s.filename),"w").write("\n".join(body)+"\n")
    def _sheet_obj(self, s):
        # a (sheet ...) placed on root referencing the child file
        x,y = s.root_pos
        return ('\t(sheet\n\t\t(at %s %s)\n\t\t(size 40 20)\n\t\t(exclude_from_sim no)\n\t\t(in_bom yes)\n\t\t(on_board yes)\n\t\t(dnp no)\n'
                '\t\t(uuid "%s")\n'
                '\t\t(property "Sheetname" "%s"\n\t\t\t(at %s %s 0)\n\t\t\t(effects\n\t\t\t\t(font\n\t\t\t\t\t(size 1.27 1.27)\n\t\t\t\t)\n\t\t\t\t(justify left bottom)\n\t\t\t)\n\t\t)\n'
                '\t\t(property "Sheetfile" "%s"\n\t\t\t(at %s %s 0)\n\t\t\t(effects\n\t\t\t\t(font\n\t\t\t\t\t(size 1.27 1.27)\n\t\t\t\t)\n\t\t\t\t(justify left top)\n\t\t\t)\n\t\t)\n'
                '\t\t(instances\n\t\t\t(project "%s"\n\t\t\t\t(path "/%s"\n\t\t\t\t\t(page "%s")\n\t\t\t\t)\n\t\t\t)\n\t\t)\n\t)'
                %(x,y,s.inst_uuid,s.name,x,y-1,s.filename,x,y+21,self.name,self.root_uuid,s.page))
    def write_root(self, title, comment_lines):
        comments="".join('\t\t(comment %d "%s")\n'%(i+1,c) for i,c in enumerate(comment_lines))
        body=["(kicad_sch",'\t(version 20250114)','\t(generator "kisch")','\t(generator_version "10.0")',
              '\t(uuid "%s")'%self.root_uuid,'\t(paper "A3")',
              '\t(title_block\n\t\t(title "%s")\n\t\t(date "2026-05-29")\n\t\t(rev "0.1")\n%s\t)'%(title,comments),
              self._lib_symbols_block()]
        for t in self.root_texts: body.append(self._text_block(*t))
        for s in self.sheets: body.append(self._sheet_obj(s))
        for c in self.root_powers: body.append(self._comp_block(c,None,"/%s"%self.root_uuid))
        # root sheet_instances enumerates all pages
        paths='\t\t(path "/"\n\t\t\t(page "1")\n\t\t)\n'
        for s in self.sheets:
            paths+='\t\t(path "/%s"\n\t\t\t(page "%s")\n\t\t)\n'%(s.inst_uuid,s.page)
        body.append('\t(sheet_instances\n%s\t)'%paths)
        body.append(")")
        open(os.path.join(self.outdir,self.name+".kicad_sch"),"w").write("\n".join(body)+"\n")
    def write_libtables(self):
        # symbol lib table (absolute URIs for libs actually used)
        rows=[]
        for lib in sorted(self._used):
            uri = CUSTOM_LIBS[lib] if lib in CUSTOM_LIBS else "%s/%s.kicad_sym"%(SYMDIR,lib)
            rows.append('\t(lib (name "%s")(type "KiCad")(uri "%s")(options "")(descr ""))'%(lib,uri))
        open(os.path.join(self.outdir,"sym-lib-table"),"w").write("(sym_lib_table\n\t(version 7)\n"+"\n".join(rows)+"\n)\n")
        # footprint lib table (libs referenced in Footprint fields)
        fplibs=set()
        for s in self.sheets:
            for c in s.comps:
                fp=c.fields.get('Footprint','')
                if ':' in fp: fplibs.add(fp.split(':',1)[0])
        rows=[]
        for lib in sorted(fplibs):
            if lib=="bridge":
                uri="%s/footprints/bridge.pretty"%self.outdir
            else:
                uri="%s/%s.pretty"%(FPDIR,lib)
            rows.append('\t(lib (name "%s")(type "KiCad")(uri "%s")(options "")(descr ""))'%(lib,uri))
        open(os.path.join(self.outdir,"fp-lib-table"),"w").write("(fp_lib_table\n\t(version 7)\n"+"\n".join(rows)+"\n)\n")
    def root_power(self, sym, at):
        self.use_symbol('power', sym)
        pins=pins_of(self.lib('power'),sym); pinmap={p['number']:(p['x'],p['y'],p['angle']) for p in pins}
        c=Comp("power:%s"%sym,_pwr_ref(),sym,at,pinmap); c.is_power=True
        self.root_powers.append(c); return c

if __name__ == "__main__":
    import sys
    lib, sym = sys.argv[1], sys.argv[2]
    for p in pins_of(load_lib(lib), sym):
        print(p)

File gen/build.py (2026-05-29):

#!/usr/bin/env python3
"""Generate the Universal ESP32 Button/Signal Bridge KiCad project (tidy layout).
Power + MCU + 8 inputs + 8 PhotoMOS + 2 relays + 4 cap-inject, hierarchical.
Each pin gets a short wire stub with its label/power symbol offset outward,
components spaced on a grid -> human-readable while staying ERC-clean."""
import os, shutil, kisch
from kisch import Project

ROOT = os.path.dirname(os.path.dirname(os.path.abspath(__file__)))
GEN  = os.path.join(ROOT, "gen")
shutil.copy(os.path.join(GEN, "bridge.kicad_sym"), os.path.join(ROOT, "bridge.kicad_sym"))
kisch.CUSTOM_LIBS["bridge"] = os.path.join(ROOT, "bridge.kicad_sym")

FP = dict(
    r0603="Resistor_SMD:R_0603_1608Metric", r1206="Resistor_SMD:R_1206_3216Metric",
    c0603="Capacitor_SMD:C_0603_1608Metric", c1206="Capacitor_SMD:C_1206_3216Metric",
    c0805="Capacitor_SMD:C_0805_2012Metric", l="Inductor_SMD:L_1210_3225Metric",
    led="LED_SMD:LED_0603_1608Metric", smc="Diode_SMD:D_SMC", sma="Diode_SMD:D_SMA",
    sod323="Diode_SMD:D_SOD-323", sot23="Package_TO_SOT_SMD:SOT-23",
    sot235="Package_TO_SOT_SMD:SOT-23-5", sot236="Package_TO_SOT_SMD:SOT-23-6",
    photomos="bridge:AQY212GS_SOP-4", opto="bridge:EL357N_SOP-4", relay="bridge:HK4100F-DC5V-SHG",
    usbc="Connector_USB:USB_C_Receptacle_HRO_TYPE-C-31-M-12",
    tb2="TerminalBlock:TerminalBlock_MaiXu_MX126-5.0-02P_1x02_P5.00mm",
    tb3="TerminalBlock:TerminalBlock_MaiXu_MX126-5.0-03P_1x03_P5.00mm",
    hdr3="Connector_PinHeader_2.54mm:PinHeader_1x03_P2.54mm_Vertical",
    hdr6="Connector_PinHeader_2.54mm:PinHeader_1x06_P2.54mm_Vertical",
    btn="Button_Switch_SMD:Panasonic_EVQPUJ_EVQPUA", tp="TestPoint:TestPoint_Pad_D1.5mm",
    esp="RF_Module:ESP32-S3-WROOM-1",
)

p = Project("universal-esp32-bridge", ROOT)
_ctr = {}
def ref(prefix):
    _ctr[prefix] = _ctr.get(prefix, 0) + 1
    return "%s%d" % (prefix, _ctr[prefix])

# ---- stub-based connection helpers (label/power offset from pin) ----
_ANG = {'R':0,'U':90,'L':180,'D':270}
def _end(pt,d,ln):
    x,y=pt; return {'U':(x,y-ln),'D':(x,y+ln),'L':(x-ln,y),'R':(x+ln,y)}[d]
def autodir(c,pin):
    return c.outdir(pin)  # outward direction from the pin's true orientation angle
def NL(sh,c,pin,net,d=None,ln=5.08,glob=False):
    d=autodir(c,pin)  # always route outward from the pin's true orientation
    pt=c.pin(pin); e=_end(pt,d,ln); sh.wire(pt,e)
    (sh.glabel if glob else sh.label)(net,e,angle=_ANG[d])
def GL(sh,c,pin,net,d=None,ln=5.08): NL(sh,c,pin,net,d,ln,glob=True)
def PW(sh,c,pin,sym,d=None,ln=5.08):
    d=autodir(c,pin)
    pt=c.pin(pin); e=_end(pt,d,ln); sh.wire(pt,e); sh.power(sym,e)
def NC(sh,c,pin): sh.nc(c.pin(pin))

# =============================== POWER (A3) ===============================
pw = p.add_sheet("Power", "power.kicad_sch", "Power - USB-C / diode-OR / SY8089 buck 3.3V")
pw.root_pos=(38,38)
jusb=pw.place("Connector","USB_C_Receptacle_USB2.0_16P",ref("J"),"USB-C",(60,90),footprint=FP["usbc"])
for n in ("A4","A9","B4","B9"): NL(pw,jusb,n,"VBUS",'R')
for n in ("A1","A12","B1","B12","SH"): PW(pw,jusb,n,"GND")
for n in ("A6","B6"): NL(pw,jusb,n,"USB_DP_RAW",'R')
for n in ("A7","B7"): NL(pw,jusb,n,"USB_DM_RAW",'R')
NC(pw,jusb,"A8"); NC(pw,jusb,"B8")
rc1=pw.place("Device","R",ref("R"),"5.1k",(120,45),footprint=FP["r0603"]); NL(pw,rc1,"1","CC1",'U'); PW(pw,rc1,"2","GND")
rc2=pw.place("Device","R",ref("R"),"5.1k",(150,45),footprint=FP["r0603"]); NL(pw,rc2,"1","CC2",'U'); PW(pw,rc2,"2","GND")
NL(pw,jusb,"A5","CC1",'D'); NL(pw,jusb,"B5","CC2",'D')
uesd=pw.place("Power_Protection","USBLC6-2P6",ref("U"),"USBLC6-2SC6",(120,140),footprint=FP["sot236"])
NL(pw,uesd,"1","USB_DP_RAW",'L'); NL(pw,uesd,"3","USB_DM_RAW",'L'); PW(pw,uesd,"2","GND"); NL(pw,uesd,"5","VBUS",'U')
GL(pw,uesd,"6","USB_D+",'R'); GL(pw,uesd,"4","USB_D-",'R')
d1=pw.place("Device","D_Schottky",ref("D"),"SS54",(220,50),footprint=FP["smc"]); NL(pw,d1,"2","VBUS",'U'); NL(pw,d1,"1","+5V",'D')
jext=pw.place("Connector_Generic","Conn_01x02",ref("J"),"EXT 5V",(220,110),footprint=FP["tb2"]); NL(pw,jext,"1","EXT5V",'R'); PW(pw,jext,"2","GND")
d2=pw.place("Device","D_Schottky",ref("D"),"SS54",(260,50),footprint=FP["smc"]); NL(pw,d2,"2","EXT5V",'U'); NL(pw,d2,"1","+5V",'D')
c1=pw.place("Device","C",ref("C"),"100uF",(300,50),footprint=FP["c1206"]); PW(pw,c1,"1","+5V"); PW(pw,c1,"2","GND")
c2=pw.place("Device","C",ref("C"),"100nF",(330,50),footprint=FP["c0603"]); PW(pw,c2,"1","+5V"); PW(pw,c2,"2","GND")
buck=pw.place("bridge","SY8089",ref("U"),"SY8089AAAC",(400,110),footprint=FP["sot235"])
PW(pw,buck,"4","+5V",'L'); PW(pw,buck,"1","+5V",'L',ln=10.16); PW(pw,buck,"2","GND"); NL(pw,buck,"3","SW",'R'); NL(pw,buck,"5","FB",'L')
cin=pw.place("Device","C",ref("C"),"22uF",(360,55),footprint=FP["c0805"]); PW(pw,cin,"1","+5V"); PW(pw,cin,"2","GND")
l1=pw.place("Device","L",ref("L"),"2.2uH",(470,60),footprint=FP["l"]); NL(pw,l1,"1","SW",'U'); NL(pw,l1,"2","+3V3",'D')
cout=pw.place("Device","C",ref("C"),"22uF",(500,110),footprint=FP["c0805"]); PW(pw,cout,"1","+3V3"); PW(pw,cout,"2","GND")
r3=pw.place("Device","R",ref("R"),"453k",(470,150),footprint=FP["r0603"]); PW(pw,r3,"1","+3V3"); NL(pw,r3,"2","FB",'D')
r4=pw.place("Device","R",ref("R"),"100k",(470,185),footprint=FP["r0603"]); NL(pw,r4,"1","FB",'U'); PW(pw,r4,"2","GND")
for net,x in (("+5V",300),("+3V3",340),("GND",380),("VBUS",420)):
    pw.power("PWR_FLAG",(x,230)); pw.power(net,(x,230))
for nm,net,y in (("+5V","+5V",40),("+3V3","+3V3",70),("GND","GND",100)):
    tp=pw.place("Connector","TestPoint",ref("TP"),nm,(560,y),footprint=FP["tp"]); PW(pw,tp,"1",net,'R')
pw.text("USB-C diode-OR -> SY8089 buck (2.7-5.5Vin,2A) -> 3.3V. EN tied +5V. Vout=0.6*(1+R3/R4)=3.32V.",(40,25))
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

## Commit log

2026-05-29 Initial design: Universal ESP32-S3 Button/Signal Bridge (rev 0.1)
    Paper design package for a low-voltage ESP32-S3 automation board:
    8 isolated inputs, 8 PhotoMOS dry-contact outputs, 2 relays, 4 cap-inject
    outputs. Includes design doc, BOM, block diagram, and KiCad project skeleton.
    [BOM.csv, universal-esp32-bridge.kicad_sch]
2026-05-29 Realize ERC-clean KiCad schematic (rev 0.2)
    Turn the paper design into a real KiCad 10 hierarchical schematic with
    library symbols and footprints. 6 sheets: power, MCU, and full channel
    counts (8 inputs, 8 PhotoMOS, 2 relays, 4 cap-inject) = 160 components.
    - Replace AMS1117 with SY8089 buck (2.7-5.5Vin) for Wi-Fi-peak headroom.
    - Input front-end uses 2.2k/1206 + EL357N (CRD dropped; poor LCSC stock).
    - Verify key parts against JLCPCB (ESP32-S3 C2913198, SY8089 C78988,
    AQY212GS C719745, HK4100F C12072, USB-C C165948, AO3400A C20917).
    - ERC passes 0 errors / 0 warnings; netlist verified, isolation barrier
    confirmed intact. No PCB layout yet (per request).
    - Add Python generator (gen/) th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
    [BOM.csv, capinject.kicad_sch, inputs.kicad_sch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]
2026-05-29 Add real footprints (HK4100F/AQY212GS/EL357N) + tidy schematic (rev 0.3)
    - Build datasheet-accurate HK4100F-DC5V-SHG footprint (6-pad THT) and a
    matching symbol; coil=3/4, COM=5/6, NO=1, NC=2.
    - Correct AQY212GS footprint to SOP-4 2.54mm pitch (was wrongly 1.27mm).
    - Fix EL357N LCSC code C124981->C6649 (C124981 was a trimmer pot); add
    generated SOP-4 footprint.
    - footprints/bridge.pretty generated from LCSC parts via easyeda2kicad.
    - Re-lay-out all sheets for human review: labels offset from pins via
    short stubs routed by each pin's true orientation; 8-channel sheets on
    larger pages; clean per-channel columns.
    - ERC still 0 errors / 0 warnings. Regenerated schematic.pdf, BOM, DESIGN.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
    [BOM.csv, capinject.kicad_sch, inputs.kicad_sch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]
